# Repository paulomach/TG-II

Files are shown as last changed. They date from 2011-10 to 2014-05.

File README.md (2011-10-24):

Bicycle Transmission Library
============================

These are me bachelor thesis source files. The goal of this project is to create a library and a firmware for an [arduino](http://www.arduino.cc) automated bycicle transmission.

How to use it
-------------

Still have to write this.

Contributing
------------

In the current stage I'm not open to external contribution, mainly because now my goal is to customize it to my test scenario (and obtain my bachelor :) ). After I finished my thesisI'll be able to check your contibution. But if in the meantime you want to use the sources, please, do it. The code is released under [GPL v3](http://www.gnu.org/licenses/gpl-3.0.html).

Tips
----
Nice svg repository with circuit components [here](http://www.nemsim.com/ece395blimp/fritzing/parts/svg/core/breadboard/)

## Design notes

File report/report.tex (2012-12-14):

%
% report.tex - tex model of graduation work
% Version 0.1
%
% Author: Paulo S. Machado
% Date: 2S 2011
%
% Release under de GNU Public License v3.0 or greater
% This library is free software; you can redistribute it and/or
% modify it under the terms of the GNU General Public
% License as published by the Free Software Foundation; either
% version 3.0 of the License, or (at your option) any later version.
% 
% This template is distributed in the hope that it will be useful,
% but WITHOUT ANY WARRANTY; without even the implied warranty of
% MERCHANTABILITY or FITNESS FOR A PARTICULAR PURPOSE.  See the GNU
% General Public License for more details.
% 
% You should have received a copy of the GNU Lesser General Public
% License along with this template; if not, write to the Free Software
% Foundation, Inc., 51 Franklin St, Fifth Floor, Boston, MA  02110-1301  USA
%
\documentclass[a4paper,11pt]{article}

\input{preamble.tex}

\parindent 1cm

% \parskip 5pt

\begin{document}

% Title page and table of contents
\input{title/title.tex}

\lstset{frame=single,
    showstringspaces=false,
    extendedchars=true,
    language=C++,
    backgroundcolor=\color[rgb]{0.95,0.95,0.95},
    rulecolor=\color[rgb]{0.3,0.3,0.3},
    basicstyle=\scriptsize\ttfamily,
    commentstyle=\color[RGB]{105,105,105}\rmfamily\itshape,
    keywordstyle=\color[rgb]{0.6,0.0,0.0}\bfseries,
    stringstyle=\color[rgb]{0.6,0.4,0.4},
    identifierstyle=\color[rgb]{0.0,0.0,0.5},
    basicstyle=\tiny,
    numbers=left,
}

%%%
%
\section{Resumo}
\label{sec:resumo}
Um trabalho de graduação em Engenharia de Controle e Automação deve,
idealmente, abranger as três grandes áreas que originam a
formação\cite{enciclo}: Engenharia Elétrica (eletrônica, processamento de
sinais, circuitos elétricos e teoria de controle, etc); Engenharia
Mecânica (dinâmica, modelagem de sistemas, etc); e a Computação (automação,
controle discreto, etc).

A ideia deste projeto surgiu das observações diárias de ciclistas e do
uso da bicicleta, onde grande parte das pessoas não utiliza de
forma eficiente as marchas de suas bicicletas. Estas parecem ser
complicadas (\textit{mountain bikes} simples possuem pelo menos 18 marchas), de
difícil manejo, configuração e manutenção. Assim como em uma transmissão
automotiva, maus hábitos na sua operação -- esticar marchas, manter a mão
apoiada sobre a alavanca, entre outros -- causam desgaste precoce dos
componentes, esforços desnecessários (neste caso para ciclista) e até risco de
segurança.

O benefício primordial de qualquer automação (i.e. retirar do usuário o
controle ou parte do controle sobre o sistema que interage) é a melhora no
fluxo do processo devido ao aumento do controle sobre o sistema. Os
resultados deste benefício são, em alto nível, o aumento da qualidade,
repetibilidade e uniformidade, aplicação de estratégias ótimas de controle e
simplicidade na interação com utilizador.

Este relatório apresenta o desenvolvimento e resultados do trabalho proposto e
estudado na primeira disciplina de Trabalho de Graduação: a construção de um
protótipo funcional de um sistema de troca de marchas automatizados para
bicicletas convencionais. Neste primeiro trabalho foram construídas as base
teóricas e ferramentais para a construção de um protótipo funcional: construção
da bancada experimental; desenvolvimento da lógica; e estudo de soluções 
existentes. Ou seja, dados os objetivos do projeto -- software de controle,
circuito de controle, atuador mecânico e a junção destes no protótipo --
apresenta-se o caminho percorrido até o objetivo e os resultados alcançados.

O documento foi estruturado de forma a descrever o problema de engenharia, as
alternativas consideradas, escolhas e desenvolvimento de cada parte funcional do
protótipo final, testes e resultados.

\pagebreak
%%%
%
\section{Introdução}
\label{sec:intro}
A tônica no início do desenvolvimento deste projeto deu-se na escolha entre a
solução usando controle ou usando automação. A solução de controle -- através
do modelamento matemático do sistema físico -- é mais elegante, porém seu
desenvolvimento é mais complexo e depende de um sinal contínuo. A automação
-- análise dos sinais e programação de reações -- não é tão elegante e
eficiente, porém seu desenvolvimento é mais simples e pode ser orientada a
eventos. A resposta, seja ela qual for, passa obrigatoriamente pela análise do
problema físico.

\subsection{Análise do problema físico}
A transmissão ciclística convencional é apresentada na Figura
\ref{fig:transmissao}.
\begin{figure}[ht]
\begin{center}
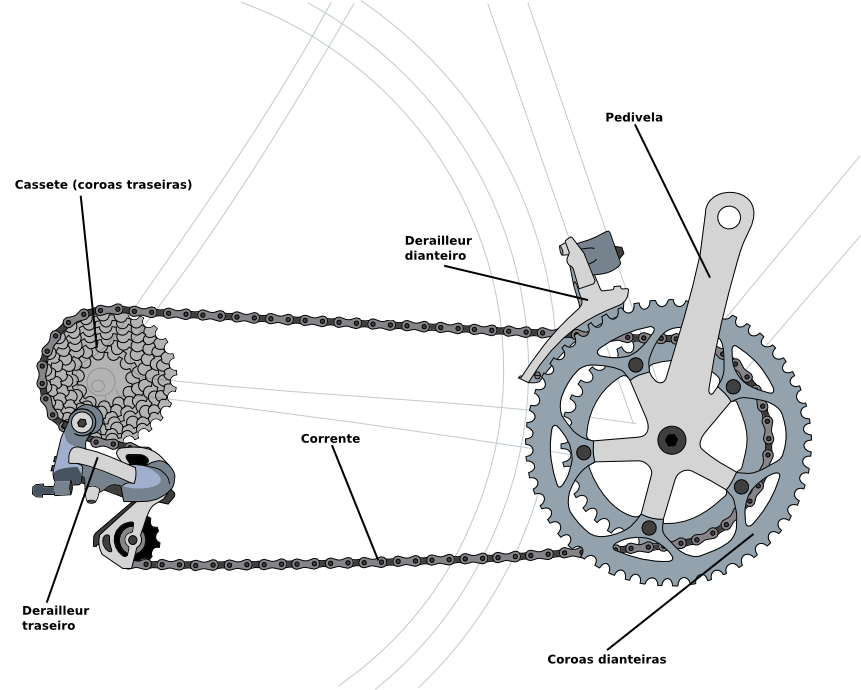
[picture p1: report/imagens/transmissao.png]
 
\end{center}
  \caption{Componentes de uma transmissão ciclística}
  \label{fig:transmissao}
\end{figure}
Podemos observar os principais componentes da transmissão, sendo na ordem em que
a energia é transmitida: o pedivela transmite o torque aplicado aos pedais pelo
ciclista às coroas dianteiras, que movimentam a corrente, que por sua vez,
transmite a energia às coroas traseiras (o conjunto destas é chamado de cassete,
nome que será usado no documento), conectadas a roda traseira, gerando a
movimento.

A relação de transmissão é determinada pela quantidade de dentes da coroa
traseira e dianteira de um engrenamento. Assim, a troca de marcha
(i.e. da relação de transmissão) é realizada pela mudança no engrenamento da
corrente com as coroas, tanto dianteiras  quanto traseiras. Portanto uma
bicicleta possui tantas marchas quanto forem a multiplicação da quantidade de
coroas no cassete pelas coroas dianteiras, por exemplo, quando há três coroas
dianteiras e seis coroas no cassete, a transmissão possui 3x6=18 marchas.
A mudança no engrenamento é realizado pelos
\textit{derailleurs}\footnote{\textit{Derailleur} é um termo francês que pode
ser traduzido como o ato do descarrilamento de um trem na ferrovia. O
dispositivo ganhou esse nome devido à semelhança com o evento ("descarrila" a
corrente).}, que mediante ao deslocamento longitudinal ao eixo da roda força a
corrente ser engrenada em outra coroa.

No desenvolvimento do protótipo (tratado como uma prova de conceito), por
simplicidade, a atuação foi limitada nos componentes da parte traseira
da transmissão, ou seja, apenas no \textit{derailleur} traseiro.
O esquema da Figura \ref{fig:derailleur} apresenta a visão traseira
do \textit{derailleur} e três exemplos de engrenamento.
\begin{figure}[ht]
\begin{center}
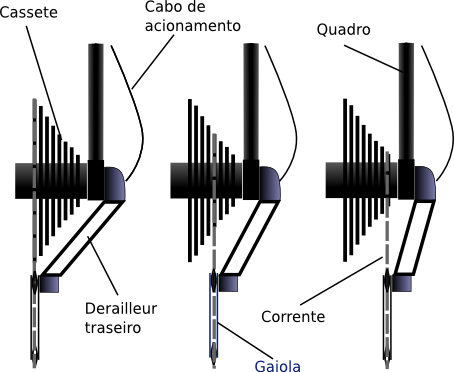
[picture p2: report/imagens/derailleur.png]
 
\end{center}
  \caption{Visão traseira de engrenamentos de um \textit{derailleur}.}
  \label{fig:derailleur}
\end{figure}
Na Figura \ref{fig:derailleur} temos, respectivamente, engrenado uma marcha
lenta (alto torque e baixa velocidade), uma marcha média e uma marcha rápida
(baixo torque e alta velocidade). O movimento da gaiola (componente do
\textit{derailleur}) se dá pela sua estrutura de braços paralelos do
\textit{derailleur} e é acionado via cabo, com retorno por mola. O cabo é
controlado pelo ciclista, geralmente por um sistema alavanca montado no guidão,
mas que também assume diversas outras formas, sempre com o objetivo de puxar ou
soltar o cabo, e genericamente chamado trocador (\textit{shifter}). O
trocador movimenta o cabo em estágios discretos, sendo cada estágio desse
correspondente ao engrenamento em uma coroa diferente.

O ciclista controla a pedalada de acordo com seu gosto, terreno e
velocidade. Logo, quando está em um aclive, procura puxar o cabo de forma a
engrenar as marchas mais lentas, e o oposto quando enfrenta um declive ou um
terreno que ofereça menos resistência, como por exemplo asfalto plano. O gosto e
biótipo do ciclista determinam o ponto da troca de marcha pela velocidade da
cadência (velocidade da pedalada). Por exemplo, o sete vezes campeão do
\textit{Tour de France}, Lance Armstrong, prefere pedalar em alta velocidade
(picos de 100-110 RPM), enquanto que outros ciclistas de sua categoria
dificilmente alcançam 90 RPM de
cadência\footnote{
\url{http://www.trifuel.com/training/bike/cycling-cadence-and-pedaling-economy}}
. Ciclistas amadores possuem limites bem inferiores. Portanto, uma premissa
básica
do projeto é a possibilidade do ajuste sobre os limites para a troca de marcha.

O resultado da análise do problema físico levou a escolha pela solução de
automação, preterindo o controle. A decisão baseou-se na observação de que o
sistema de uma transmissão de bicicleta, considerando as possíveis alternativas
para a forma de aquisição de dados de custo acessível, é orientado a
eventos e baseado em estados discretos.

\subsection{Revisão bibliográfica}
Uma ampla revisão bibliográfica foi realizada na primeira parte deste Trabalho
de Graduação, e não será repetida neste relatório. Vale ressaltar porém, que
pouca bibliografia acadêmica é produzida sobre o assunto. Por outro lado, o
desenvolvimento comercial é bastante prolífico, havendo em torno de quatro ou
cinco companhias multinacionais liderando os mercados globais de componentes e
diversos garagistas pensando e desenvolvendo soluções.

A maior dificuldade é como localizar documentação sobre uma solução tão
específica. A solução foi a utilização de duas bases de patentes:
USPTO\cite{uspto} e EPO\cite{epo}. O critério de escolha utilizado para
selecionar apenas os dois escritórios foi o fato de constituírem os dois maiores
mercados consumidores do mundo.

\subsection{Premissas do projeto}
\label{sec:premissas}
Após o estabelecimento do tipo de solução e de alguns requisitos mínimos, quatro
premissas simples foram estabelecidas para o protótipo. São:
\begin{itemize*}
  \item Baixo custo
  \item Adaptabilidade ao sistema existente
  \item Possibilidade de configuração de parâmetros
  \item Interface com usuário
\end{itemize*}

\pagebreak
%%%
%
\section{Desenvolvimento das partes}
\label{sec:partes}
Nesta seção são apresentadas as partes do projeto e como estas foram unidas. O
desenvolvimento deste projeto foi modular, o que permitiu na maior parte do
tempo trabalhar no hardware e no software de forma independente. As partes são:
\begin{itemize*}
  \item Bancada experimental
  \item Circuito de controle
  \item Protótipo Completo
  \item Algoritmo de Controle
\end{itemize*}

\subsection{Bancada experimental}
\label{sec:bancada}
A bancada experimental é um dos produtos principais da primeira parte deste
trabalho de graduação. Simular os sinais do sistema via algum tipo de software
ou kit é uma opção menos desejável, visto que o de desenvolvimento
do projeto com base em um sistema real não se apresentou como uma proposta
complicada ou muito cara. Desta forma, a solução elaborada no primeiro trabalho
foi usar uma bicicleta convencional e adaptá-la de forma a criar uma bancada de
testes. O resultado é apresentado na Figura
\ref{fig:bancada}.
\begin{figure}[ht]
 \begin{center}
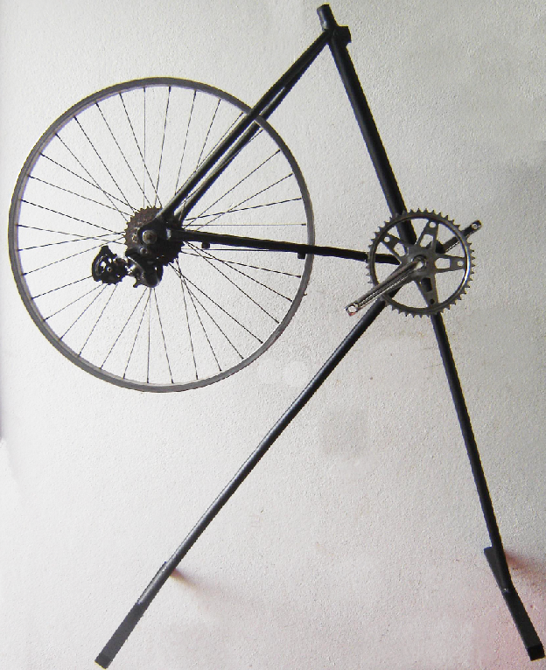
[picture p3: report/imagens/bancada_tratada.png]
  
 \end{center}
 \caption{Bancada experimental construída para o TG I}
 \label{fig:bancada}
\end{figure}
A bancada é uma meia bicicleta -- com a parte traseira, onde estão os
elementos da transmissão  -- onde foram soldados apoios, possibilitando
``pedalar no vazio'' e realizar os testes do projeto em um sistema real.

Foram diversos os problemas relativos a bancada, e surgiram no momento prévio
aos testes, quando os componentes da transmissão foram montados. As peças
disponíveis não eram compatíveis (corrente curta, coroa dianteira
não casou com o corrente), o que causou novos custos e atraso nos testes.
Superados os percalços, o resultado final é apresentado na Figura
\ref{fig:setup}. Nesta montagem estão presentes, além do sistema mecânico
completo da bicicleta, a montagem do servo motor e os ímas acoplados ao
pedivela e a roda.
\begin{figure}[h!]
\begin{center}
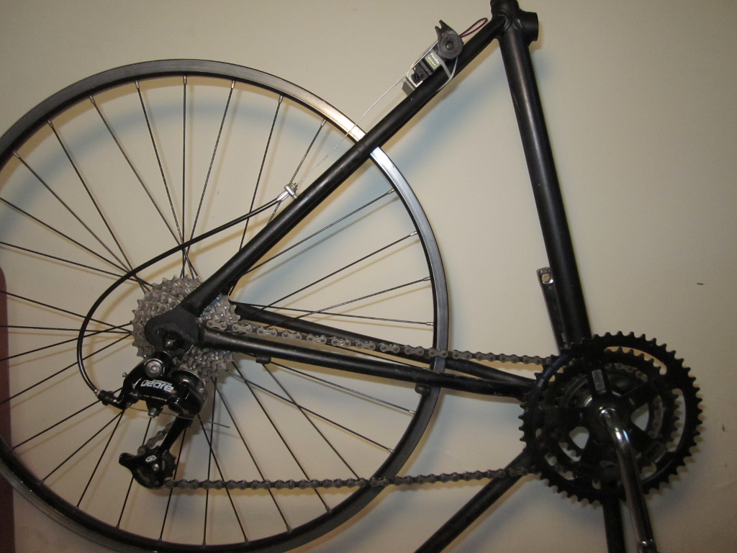
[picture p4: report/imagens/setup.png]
 
\end{center}
  \caption{Bancada pronta para teste}
  \label{fig:setup}
\end{figure}

%%%
%
\subsection{Circuito de controle}
\label{sec:montagem}
O circuito de controle foi montado sobre uma placa de prototipação (protoboard)
e seu esquema geral é apresentado na Figura \ref{fig:montagem}.
Os componentes podem ser separados em três grupos funcionais: saídas, controle
e entradas.
\begin{figure}[ht]
\begin{center}
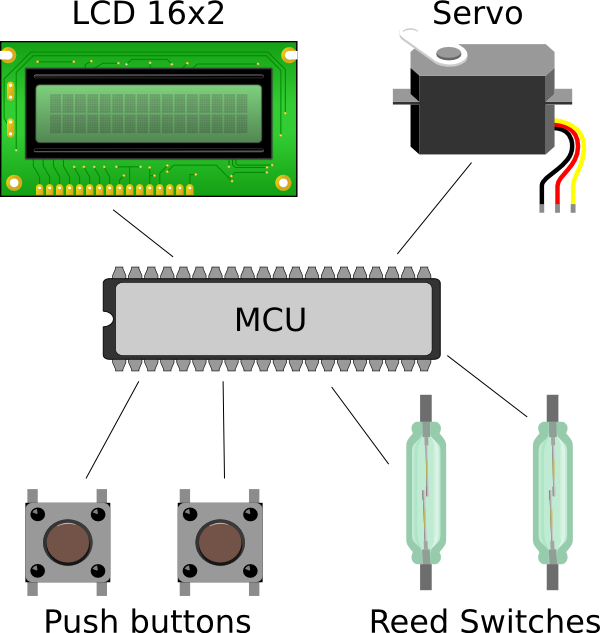
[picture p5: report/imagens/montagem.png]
 
\end{center}
  \caption{Componentes da montagem do circuito de controle}
  \label{fig:montagem}
\end{figure}
Nessa classificação são: saídas, servo motor e LCD (\textit{Liquid
Crystal Display}); controle, MCU (\textit{MicroControler Unit}); e entradas os
\textit{push buttons} e \textit{reed switch}. Os componentes utilizados e
detalhes da integração são descritos a seguir.

\subsubsection{Servo Motor}
\label{sec:servo}
O servo motor é o único atuador deste projeto, sendo responsável pela atuação
sobre o cabo do \textit{derailleur} e consequente troca de marchas. Duas
perguntas foram elaboradas para ajudar na definição de um atuador: Qual a
forma mais simples de atuar sobre um cabo utilizando um motor rotativo? Qual
tipo de motor é confiável e fácil de controlar? A reposta, encontrada a partir
do estudo realizado na primeira parte do trabalho de graduação, é o
acoplamento de uma polia (atuador sobre cabo) a um servo motor.

O raio da polia foi dimensionado de tal forma que, dado que um servo motor
rotaciona 180\textdegree, meia circunferência da polia seja deslocamento
suficiente para movimentar o \textit{derailleur} da menor a maior marcha.
Assim, definimos o raio da polia ($r_{polia}$), o número de marchas (n) e o
passo (p) como o deslocamento necessário do cabo de comando para a mudança de
uma marcha consecutiva, de tal forma que:
\begin{equation*}
  \frac{\displaystyle 2\pi r_{polia} }{\displaystyle 2} = (n-1)p
\end{equation*}
\begin{equation}
  r_{polia} = \frac{\displaystyle (n-1)p}{\displaystyle \pi}
\end{equation}
Para a bancada de testes, n=6 e p=3 mm. O raio ideal para a polia é:
\begin{equation}
 r_{polia} = \frac{\displaystyle (6-1)\times 3}{\displaystyle \pi} = 4,77~mm
\end{equation}
Porém, este resultado não foi utilizado, pois a construção de uma polia foi
preterida pela adaptação de um trocador manual (Figura \ref{fig:shifter}).
\begin{figure}[h!]
\begin{center}
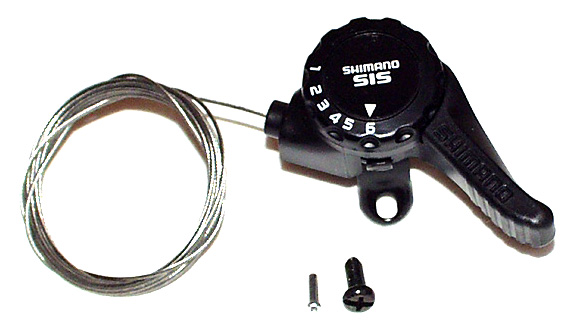
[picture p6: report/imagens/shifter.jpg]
 
\end{center}
  \caption{Trocador manual antes da adaptação}
  \label{fig:shifter}
\end{figure}

A polia interna deste trocador possui raio de 8,5 mm, o que por um lado aumenta
o intervalo de marchas disponível e a velocidade da troca (dada velocidade de
rotação constante do servo), por outro aumenta o requisito de torque no eixo. A
Figura \ref{fig:atuador} mostram a sequência da
adaptação.
\begin{figure}[h!]
 \centering
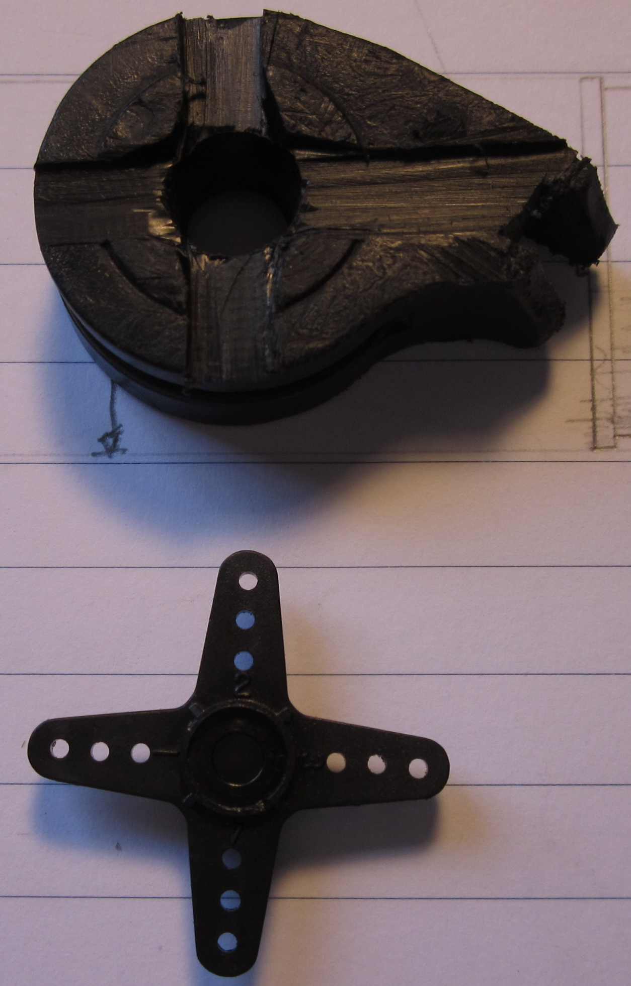
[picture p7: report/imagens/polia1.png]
  \subfloat[Partes]{} \hfil
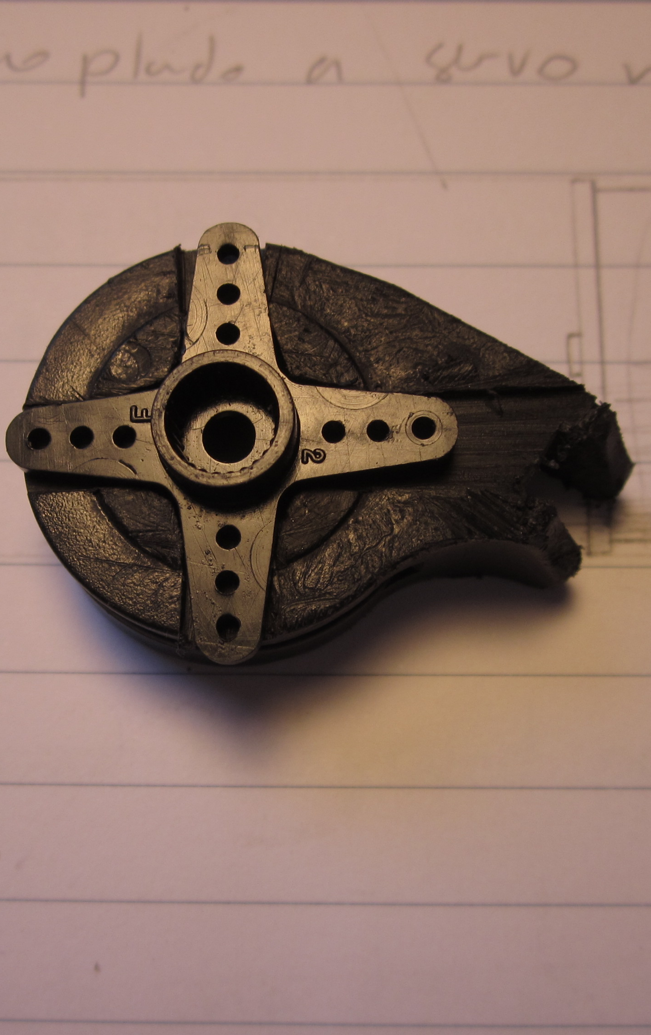
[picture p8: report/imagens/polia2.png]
  \subfloat[Partes Montadas]{} \hfil
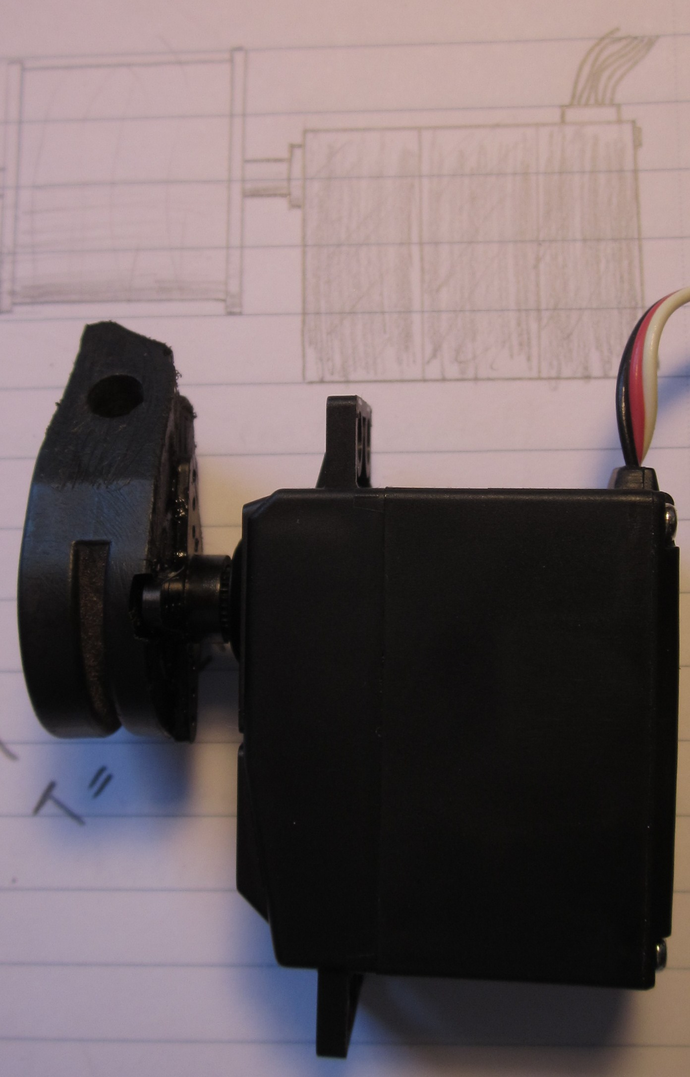
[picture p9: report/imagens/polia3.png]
  \subfloat[Atuador Completo]{}
  \caption{Sequência de adaptação do atuador}
  \label{fig:atuador}
\end{figure}

Pequenos servos RC (motores destinados ao mercado de hobbistas) são baratos,
fáceis de encontrar, robustos e seu controle é feito por um sinal PWM. O
servo motor escolhido foi um Futaba S3004, visto na Figura \ref{fig:
servo}. O S3004 possui rolamentos de esferas no eixo de saída, e torque de
4,1kg-cm a 6 volts, o que no SI equivale a $4,1 \times 9,81 \times 10^{-2} =
0,4022$ Nm.

\begin{figure}[ht]
 \begin{center}
  
 \end{center}
 \caption{Servo Futaba S3004}
 \label{fig: servo}
\end{figure}

Dois complicadores existem na utilização de servos motores\cite{servo}, em
relação a seu comportamento elétrico. O primeiro, como todo componente indutivo,
são os picos de corrente a cada mudança de posição, que podem drenar toda
corrente destinada ao controlador. O segundo complicador é o ruído, tanto gerado
pelo servo nas escovas do motor DC, quanto captado pelo cabo de sinal -- é comum
ver um servo "tremendo" quando em repouso -- pois o cabo do sinal PWM atua como
uma antena. Para mitigar estes efeitos a alimentação do servo foi isolada da
alimentação do resto do protótipo. O único cuidado adicional é manter as
referências no mesmo potencial, ou seja, manter o terra do circuito de controle
e do servo no mesmo potencial.

\subsubsection{Display LCD 16x2}
\label{sec:lcd}

Como o sistema propõe uma interface com o usuário, um display LCD foi escolhido
para executar este papel. A principal vantagem deste tipo de display é o baixo
consumo de energia, essencial em sistemas embarcados, devido a independência de
uma fonte de luz própria. O tamanho de 16 caracteres e duas linhas é suficiente
para mostrar as informações de velocidade imediata, a marcha engatada e o valor
da constante de ajuste, planejadas para esta interface.

O display utilizado é um JHD-162a\cite{lcd} de fabricante desconhecido e
facilmente encontrado no mercado, visto na Figura \ref{fig:lcd}.
\begin{figure}[ht]
\begin{center}
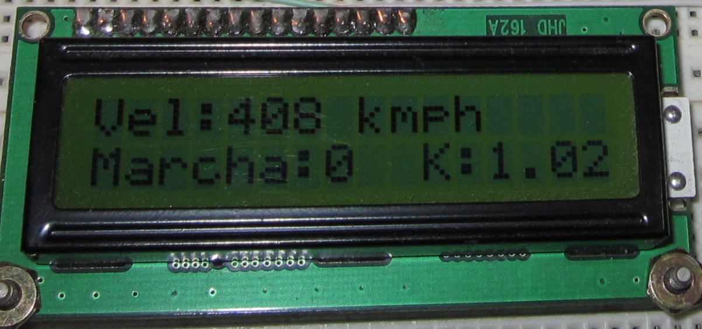
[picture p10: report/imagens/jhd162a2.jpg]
 
\end{center}
  \caption{Display LCD 16x2}
  \label{fig:lcd}
\end{figure}

A montagem do display não ofereceu nenhum problema, funcionando \textit{out of
the box}, o que é creditado a fartura de boa documentação encontrada na
Internet.

\subsubsection{Reed Switch}
\label{sec:reed}

A definição e uso de elementos sensores foi um dos elementos chave deste
projeto. Estes deveriam ser usados para a leitura de pulsos a cada revolução da
roda e do pedivela, gerando as informações de velocidades, básica ao algoritmo
de controle. As soluções analisadas foram:
\begin{itemize*}
 \item Sensor capacitivo
 \item Sensor indutivo
 \item \textit{Reed switch}
 \item Sensor de efeito HALL
\end{itemize*}
Os principais critérios de escolha, que permearam o projeto desde sua concepção,
foram simplicidade e custo. O escolhido foi o  \textit{reed switch}, que
oferece uma enorme margem de vantagem nos critérios escolhidos, e já é a
implementação padrão de computadores ciclísticos.

Um \textit{reed switch} é uma chave normalmente aberta constituída de duas
lâminas ferromagnéticas flexíveis, que sob influência de um campo magnético,
fecha o contato. A Figura \ref{fig:reed} apresenta o conceito é um
\textit{reed} como os utilizados.

\begin{figure}[h!]
 \centering
  \subfloat[Uma ampola \textit{reed} e
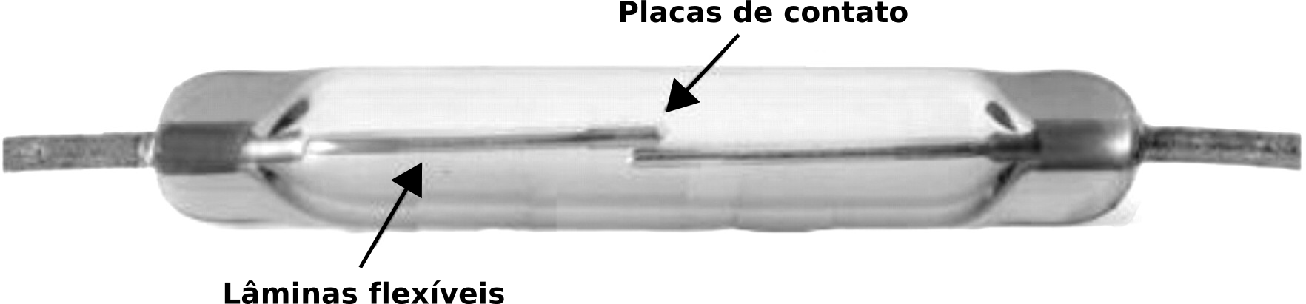
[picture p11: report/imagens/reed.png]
partes.]{} \hfil
  \subfloat[Contato fecha com
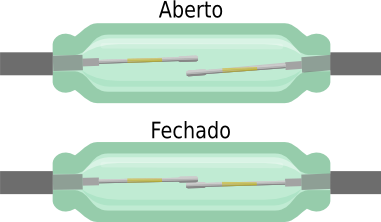
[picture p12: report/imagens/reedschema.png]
influência de campo magnético.]{}
  \caption{O \textit{Reed Switch}.}
  \label{fig:reed}
\end{figure}

Um problema grave dos \textit{reed switch} é o ruído gerado na
sua operação. Devido ao \textit{bouncing}\cite{reed} o sinal gerado precisa de
um tratamento para que possa ser lido corretamente. Foi considerado realizar o
\textit{debounce} do sinal de duas formas: via software; ou via hardware. A
primeira foi descartada pois as funções do programa responsáveis pelo
cálculo de velocidade seriam rotinas de interrupção, ou seja, eles devem ter uma
execução muito breve, caso contrário podem afetar a contagem de tempo do
sistema e uma função de \textit{debounce} em software envolve, inerentemente
algum \textit{delay}.

\begin{figure}[ht]
 \begin{center}
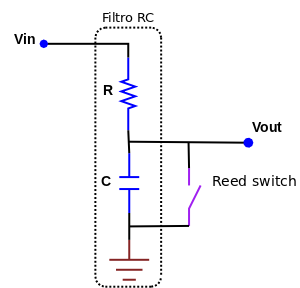
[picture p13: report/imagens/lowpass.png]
  
 \end{center}
 \caption{Filtro passa-baixa passivo acoplado ao \textit{reed switch}}
 \label{fig:lowpass}
\end{figure}

A alternativa foi implementar o \textit{debounce} em hardware, utilizando
um filtro passa-baixa passivo, que usa apenas um resistor e um capacitor, de
acordo com o esquema da Figura \ref{fig:lowpass}. O ruído de um \textit{reed
switch} comum está na faixa de 1500Hz a 2000Hz\cite{reed}. É possível estimar a
frequência máxima ($f_{max}$) de ativação dos \textit{reeds} a partir de um
limite de velocidade da roda ($v_{max} = 90 km/h = 25 m/s$):
\begin{equation}
  v = \omega r = 2\pi f r \Rightarrow v_{max} = 2\pi f_{max} r
\end{equation}
O diâmetro da roda com pneu foi medido em d=65cm = 0,65m. Portanto, para
velocidade máxima de 90 km/h:
\begin{equation}
  f_{max} = \frac{\displaystyle v_{max}}{\displaystyle \pi d} =
\frac{\displaystyle 25}{\displaystyle \pi 0,65} = 12,243 Hz
\end{equation}
Tomando a frequência de corte ($f_{c}$) dada pela relação,
\begin{equation}
  f_{c} = \frac{\displaystyle 1}{\displaystyle 2\pi\tau} \text{, onde } \tau =
RC
\end{equation}
igual a frequência máxima ($f_{max}$), diversas combinações de resistores e
capacitores são possíveis. Logo, o script \ref{code:filter} escrito em
linguagem pyhton\cite{python} foi usado para ajudar a dimensionar os
componentes, de acordo com o que foi adquirido (Sec. \ref{custos}) e o que foi
obtido.

\subsubsection{Push buttons}
\label{sec:buttons}
Os \textit{push buttons} têm a função de modificação da constante de ajuste do
sistema, incrementado ou decrementando seu valor. São elementos bastante
simples, que como os \textit{reed switch}, produzem ruído pelo fenômeno de
\textit{bouncing}. Porém como a sua aplicação não é crítica, não houve a
preocupação em tratar o sinal, pois o funcionamento do sistema praticamente não
é prejudicado por estas falhas.
\begin{figure}[ht]
\begin{center}
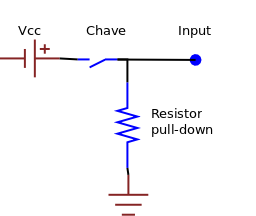
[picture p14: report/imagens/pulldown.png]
 
\end{center}
  \caption{Resistor \textit{pull-down}}
  \label{fig:pulldown}
\end{figure}

A única observação feita em relação a montagem dos \textit{push buttons} é a
topologia \textit{pull-down} do resistor, mostrado na Figura \ref{fig:pulldown}.
Este dispositivo é usado para limitar a corrente que passa do $V_{cc}$ para o
terra, e para garantir que o nível lógico seja coerente quando a chave conectada
está inativa, ``puxando'' a corrente para o terra. Tipicamente utiliza-se valor
de resistência de 10k$\Omega$, o que foi respeitado na montagem.

\subsubsection{Microcontrolador (MCU)}
\label{sec:mcu}
O microcontrolador utilizado é um ATMega168 20PU do fabricante
Atmel\textsuperscript{\textregistered}. O ATMega168\cite{atmega} é um
microcontrolador de 8 bits com 16K bytes de memória de programa e clock de 20MHz
e arquitetura RISC. O ATMega168 possui diversos periféricos dentre os quais são
de interesse para o projeto:
\begin{itemize*}
  \item 6 canais PWM
  \item 23 I/O programáveis (digitais e analógicos)
  \item Interrupção e \textit{wake-up} na borda de subida ou descida de sinal
  \item Interface serial para programação
\end{itemize*}

A utilização direta do microcontrolador requer diversos cuidados em relação a
sua alimentação, configuração de pinagem e recursos. Qualquer desenvolvedor de
sistemas embarcados sabe que este tipo de cuidado toma grande quantidade de
tempo e pode ser fonte de infindáveis problemas. Como resolver problemas de
natureza eletrônica e configuração de bits não é o propósito deste trabalho,
foi feita a escolha por uma plataforma de prototipagem que resolve grande parte
deste problemas: o Arduino\cite{arduino}\cite{oxer2009practical}.

O Arduino é uma plataforma de prototipagem \textit{open-source} (hardware e
software) que utiliza microcontroladores Atmel Mega168, Mega328 e Mega1280. Além
dos recursos providos pelo microcontrolador, são embarcados conversor
USB/Serial, tornando desnecessária uma porta serial no PC de desenvolvimento,
\textit{bournes} para conexão dos pinos de I/O, botão de \textit{reset},
cristal oscilador externo e entrada de alimentação. O circuito é capaz
de selecionar automaticamente qual fonte de alimentação utilizar (USB ou fonte
externa).

O modelo de escolhido para este trabalho foi o \textit{Duemilanove}, que
utiliza o microcontrolador ATMega168, e pode ser visto na Figura
\ref{fig:duemilanove}.
% FOTO Duemilenove
\begin{figure}[h]
\begin{center}
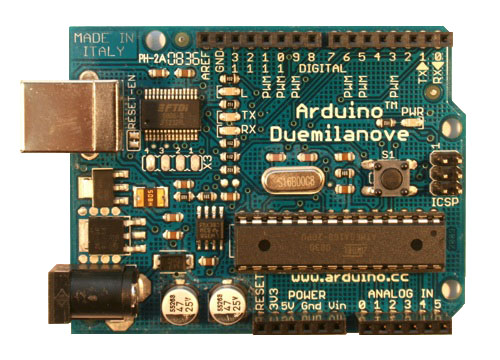
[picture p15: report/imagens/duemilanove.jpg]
 
\end{center}
  \caption{Arduino Duemilanove}
  \label{fig:duemilanove}
\end{figure}

A linguagem de programação utilizada é o C/C++, sendo que o compilador
utilizado foi o GNU Compiler Collection, o GCC\cite{gcc}. Uma das grandes
vantagem da utilização do GCC é ser multiplataforma, além do fato de ser
software livre. O Arduino provêm uma IDE e bibliotecas\cite{libs} para o
desenvolvimento de aplicações, adicionais as bibliotecas C fornecidas com o
compilador\cite{libc}, das quais foram utilizadas no projeto as bibliotecas
\textit{Servo} e \textit{LiquidCrystal}, responsáveis pela manipulação de servo
motores e display LCD, respectivamente.

%%%
%
\subsection{Protótipo}
\label{sec:prototipo}
O circuito completo do projeto, conforme esquematizado na Figura
\ref{fig:fritzing} é apresentado na Figura \ref{fig:circuito}. Um
componente adicional é o potenciômetro, usado para regular o contraste
do display LCD. Destaca-se na metade superior direita da Figura
\ref{fig:circuito} os circuitos para tratamento das entradas (dois filtros
passa-baixa e duas montagens de resistor \textit{pull-down}), e a alimentação
separada do servo motor para evitar a drenagem de corrente e ruído causado pelo
mesmo (Figura \ref{fig:fritzing}).

\begin{figure}
\begin{center}
 
\end{center}
  \caption{Esquema de montagem com protoboard}
  \label{fig:fritzing}
\end{figure}

\begin{figure}[hb!]
\begin{center}
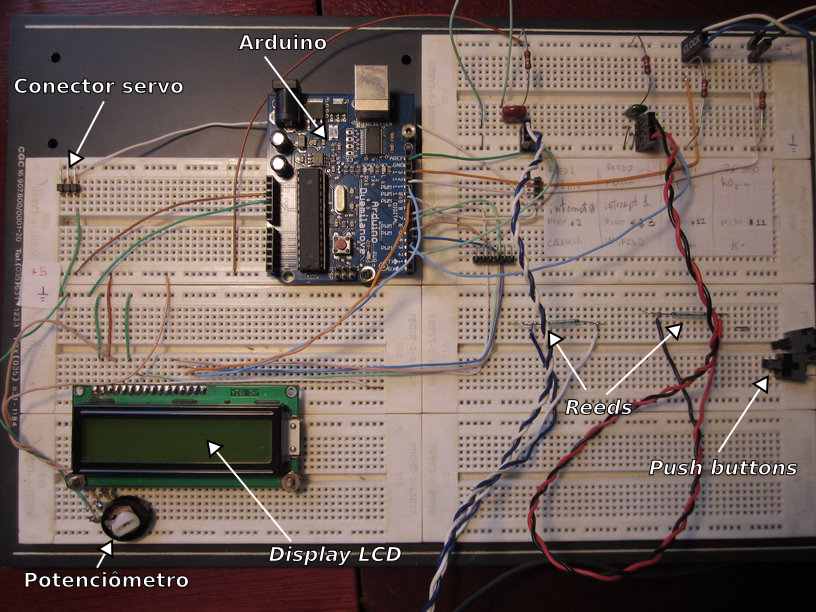
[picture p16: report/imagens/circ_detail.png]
 
\end{center}
  \caption{Circuito completo do Projeto}
  \label{fig:circuito}
\end{figure}

%%%
%
%\pagebreak

\subsection{Algoritmo de controle}
\label{sec:software}
A lógica do programa, elaborada ainda na primeira parte deste trabalho e que se
manteve fiel ao design original é apresentada na Figura \ref{fig:fluxograma1} e
descrita a seguir.

\begin{figure}[hb!]
 \begin{center}
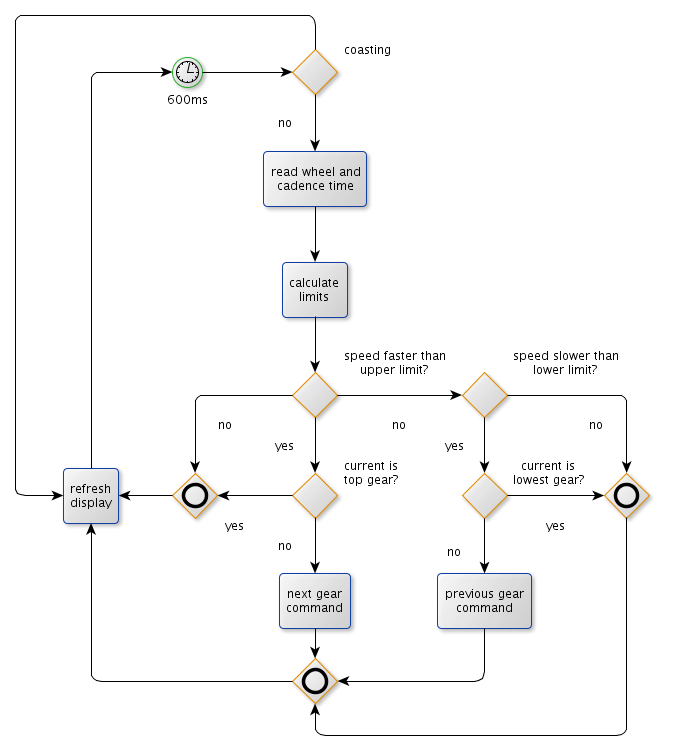
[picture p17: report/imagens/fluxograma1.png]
  
 \end{center}
 \caption{Lógica do programa de automação da transmissão}
 \label{fig:fluxograma1}
\end{figure}

\begin{description*}
  \item[Inicio:] início do programa.
  \item[Pedalando:] recebe informação da cadência e se nula, significa que o
  ciclista não está pedalando. Nesse caso, o sistema passa para o teste de
  bateria  e atualização do display. Caso contrário, segue para o passo
  seguinte, de  leitura de velocidade.
  \item[Leitura de velocidade:] armazena a leitura de velocidade instantânea do
  sensor de velocidade da roda traseira.
  \item[Calcula limites:] a partir de uma tabela de limites padrão e do valor da
  constante de velocidade (variável que armazena o valor do multiplicador dos
  limites, para adequação ao estilo de pedalada do ciclista), é calculado o
  limite de velocidade inferior e superior para a marcha presente.
  \item[Velocidade além do limite superior para a relação:] compara leitura de
  velocidade da roda traseira com o calculo do limite superior de velocidade
  para a marcha.
  \item[Velocidade abaixo do limite inferior para a relação:] compara leitura de
  velocidade da roda traseira com o calculo do limite inferior de velocidade
  para a marcha.
  \item[Próxima coroa disponível:] checa se a coroa atual engrenada é a última
  (coroa
  com menos dentes, ou seja, de maior velocidade).
  \item[Coroa anterior disponível:] checa se a coroa atual engrenada é a
  primeira (coroa com mais dentes, ou seja, de maior torque).
  \item[Movimenta \textit{derailleur} para próxima coroa:] caso a velocidade
  seja  maior que o limite superior da coroa atual e exista a próxima coroa, o
  \textit{derailleur}  é movimentado para engatar a coroa seguinte.
  \item[Movimenta \textit{derailleur} para coroa anterior:] caso a velocidade
  seja  menor que o limite inferior da coroa atual e exista a coroa anterior, o
  \textit{derailleur}  é movimentado para engatar a coroa anterior.
  \item[Checa bateria:] testa a carga da bateria e armazena informação. Esta é
  uma etapa muito importante em qualquer dispositivo embarcado, pois é da
  bateria que vem a energia necessária ao funcionamento do sistema.
  \item[Atualiza display:] atualização da interface com informação de velocidade
  instantânea, marcha engatada, e carga da bateria.
\end{description*}

\subsubsection{Estrutura do Código}
\label{sec:implemt}

A estrutura do código está dividida entre uma biblioteca, onde foram modeladas
classes para a representação do \textit{derailleur} e da roda de bicicleta, o
um programa principal. Esta opção se pauta em dois princípios, um técnico e
outro filosófico, respectivamente: utilizar a característica de representação do
mundo físico oferecida pelo programação orientada a objetos; a posterior
redistribuição do código como software livre\footnote{Todo código fonte deste
trabalho, inclusive este relatório, está disponível no site de hospedagem de
código github (\url{https://github.com/paulomach/TG-II}) sob a licença GPL
v3\cite{gpl}.}, visando a expansão e melhoria do projeto.

Fisicamente, os arquivos estão organizados:

\begin{verbatim}
BikeTransmission/
|-- BikeTransmission.cpp
|-- BikeTransmission.h
`-- keywords.txt
principal/
`-- principal.pde
\end{verbatim}

Os arquivos $BikeTransmission$ são a interface e implementação da biblioteca
que modela os elementos físicos do projeto. O arquivo $keywords.txt$ é o arquivo
de configuração para o destaque das palavras chaves introduzidas pela biblioteca
na IDE do Arduino. O arquivo $principal.pde$ é o programa principal onde a
biblioteca do projeto é usada.

A biblioteca \textit{BikeTransmission} modela basicamente duas classes que
representam a roda e o \textit{derailleur}. Um diagrama UML das classes está na
Figura \ref{fig:uml} a seguir.

\begin{figure}[h!]
\begin{center}
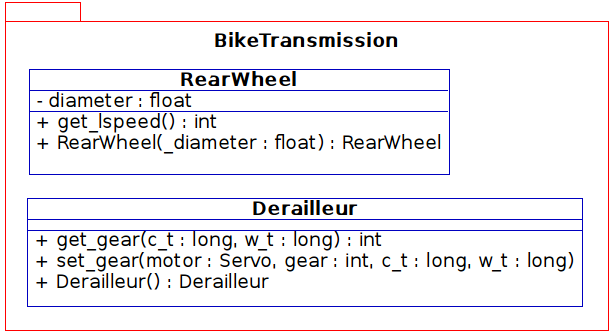
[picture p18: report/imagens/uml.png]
  
\end{center}
  \caption{Representação UML da biblioteca \textit{BikeTransmission}}
  \label{fig:uml}
\end{figure}

A roda traseira ($RearWheel$) possui um atributo representando o diâmetro da
roda, e um método para calcular a velocidade linear, além do método construtor.
O \textit{derailleur} possui dois métodos, um para obter a marcha engatada
($get\_gear$), e outro para selecionar uma nova marcha ($set\_gear$). Utiliza o
construtor padrão, pois não há configurações especiais.

O código integral está nos Anexos, nas seções \ref{code:api}, \ref{code:impl} e
\ref{code:main}, que são respectivamente, API (\textit{Application Programming
Interface}), a implementação da API e o código do programa principal que
utiliza a API. Os detalhes da implementação estão descritos na seção
\ref{sec:resultados} Testes e Resultados e especialmente na seção
\ref{sec:code_detail}, pois o desenvolvimento do código foi indissociável dos
testes.

\pagebreak
%%%
%
\section{Testes e Resultados}
\label{sec:resultados}

\subsection{Teste Preliminar}

Para início dos testes, antes de finalizada a bancada, um esquema de testes
físicos auxiliar era necessário. O objetivo é de alguma forma obter os sinais
que seriam obtidos pelo sistema real, ou seja, gerar os acionamentos dos
\textit{reed switch's} com as frequências esperadas para o sistema real.

Para satisfazer esse requisito de teste, uma plataforma foi desenvolvida
utilizando baterias, pequenos motores DC, potenciômetros (para regulação da
tensão nos motores, e logo sua velocidade), algumas peças de
LEGO\textsuperscript{\textregistered} para a montagem, e um par de ímãs
acoplados para o acionamento dos \textit{reed's}. A plataforma finalizada pode
ser vista em ação na Figura \ref{fig:test1}.

\begin{figure}[h!]
\begin{center}
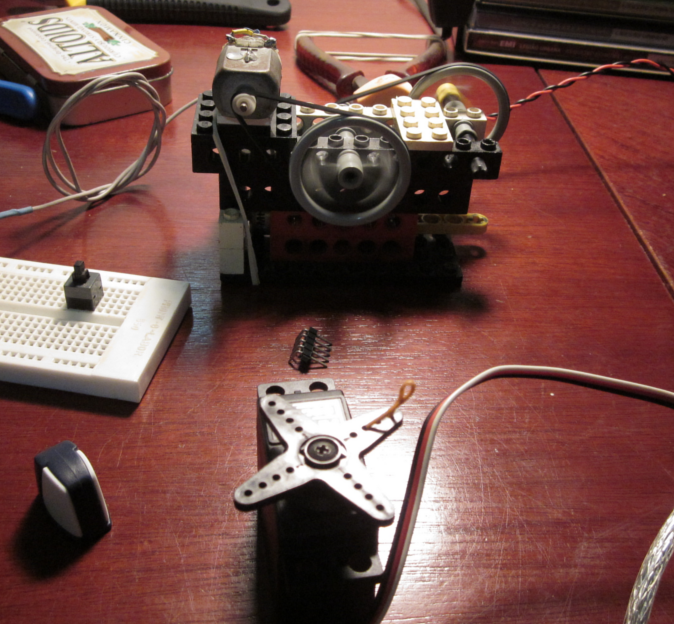
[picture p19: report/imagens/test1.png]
 
\end{center}
  \caption{Plataforma de testes}
  \label{fig:test1}
\end{figure}

Na parte de trás, o par trançado vermelho e preto é o cabeamento de um
\textit{reed}, enquanto que o \textit{protoboard} branco no centro à esquerda é
o circuito de controle da velocidade do motor DC. Acoplado a polia de trás há
um pequeno ímã de neodímio (também conhecido como ímã de terras raras),
extraído de um disco rígido. Este é um ímã poderoso considerando seu tamanho, e
gera o campo magnético necessário a ativação do \textit{reed} a até
aproximadamente 5 mm de distância.

Essa montagem permitiu a geração de um sinal em uma das duas entradas do
sistema, sendo que a segunda entrada foi gerada manualmente com outro ímã de
neodímio. As limitações desta montagem surgiram rapidamente. Gerar o sinal
manualmente se mostrou pouco conveniente, pois é bastate difícil manter um
intervalo regular manualmente. E visto que o potenciômetro disponível se
apresentou pouco amigável, se comportando mais como um interruptor do que como
uma resistência variável, não foi possível obter a variação na velocidade
desejada.

\subsubsection{Debugando o código}

Para visualizar o funcionamento e \textit{debug} do código, apenas observar a
saída do sistema (movimentação do servo motor) não é suficiente. A primeira
medida é a configuração do display LCD, mapeado como na Figura
\ref{fig:schemalcd}, contendo as informações mais básicas para a verificação do
sistema. A numeração na Figura é referente a posição de cada caractere do
display. Um exemplo do mapeamento já foi dado na Figura \ref{fig:lcd}.

\begin{figure}[h!]
\begin{center}
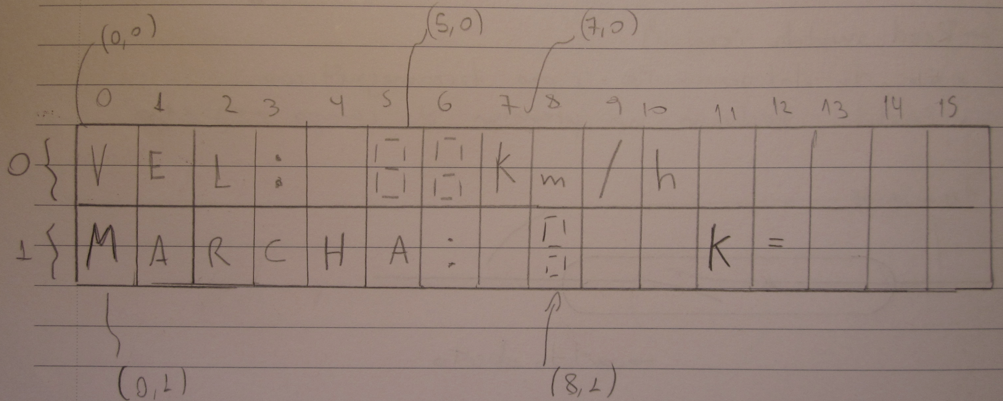
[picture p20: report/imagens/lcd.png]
  
\end{center}
  \caption{Esquema de configuração do display LCD}
  \label{fig:schemalcd}
\end{figure}

Este mapeamento é necessário para a codificação do display, apresentado no
trecho do código a seguir.
\begin{lstlisting}
  ...
  // LCD initialization
  LiquidCrystal lcd ( 7, 6, 5, 4, 8, 10 );
  ...
  // LCD static setup
  lcd.begin ( 16,2 );
  lcd.print( "start up..." );
  delay(2000);
  lcd.clear();
  lcd.print ( "Vel:" );
  lcd.setCursor ( 8,0 );
  lcd.print ( "kmph" );
  lcd.setCursor ( 0,1 );
  lcd.print ( "Marcha:" );
  lcd.setCursor ( 10,1 );
  lcd.print ( "K:" );
  ...
  // Update LCD
  void update_lcd() {
    lcd.setCursor ( 4,0 );
    lcd.print("    ");
    lcd.setCursor ( 4,0 );
    lcd.print ( wspeed );
    lcd.setCursor ( 7,1 );
    lcd.print ( gear );
    lcd.setCursor ( 12,1 );
    lcd.print ( K );
  }
...
\end{lstlisting}

O código da linha 3 cuida da instanciação de um objeto da classe LCD, usando os
pinos listados para a comunicação. Os comandos seguintes posicionam o cursor de
acordo com o mapeamento para então escrever a \textit{string} ou o valor
($lcd.setCursor$ e $lcd.print$).

Ainda assim, para o \textit{debug} do sistema mais informação é necessária. A
opção é a utilização dos recursos de comunicação serial do Arduino, que pode
transmitir dados em formato texto pela mesma porta USB usada para carregar e
alimentar o sistema. Para configurar e usar esta comunicação, o código:

\begin{lstlisting}
...
// Config Serial baud rate
Serial.begin ( 9600 );
...
/*
 * Serial debug output routine
 */
void update_serial() {
  if (debugLevel == 2) {
    Serial.print ( "Velocidade: " );    Serial.print ( wspeed );
    Serial.println(" kmph");
    Serial.print ( "Marcha: " );        Serial.println ( gear );
    Serial.print ( "Tempo roda: " );    Serial.print ( wtime );
    Serial.println (" ms" );
    Serial.print ( "Tempo cadencia: " );Serial.print ( ctime );
    Serial.println (" ms" );
    Serial.print ("K: ");               Serial.println (K);
    Serial.println("");
  }
}
...
\end{lstlisting}

Na linha 3 é configurado o \textit{baud rate}, que na comunicação serial
equivale a quantidade de bits transferida por segundo. O terminal serial
utilizado na leitura das mensagens precisa ter o mesmo \textit{baud rate}. A
partir da linha 8 a rotina de comunicação serial só transmite caso uma flag
seja configurada para tal.

Em qualquer parte do código pode ser adicionado um comando de impressão serial,
contendo o valor de uma variável, uma informação textual ou ambos. Um exemplo
dos das informações normalmente impressas na saída serial está na Figura
\ref{fig:serial}.

\begin{figure}[h!]
\begin{center}
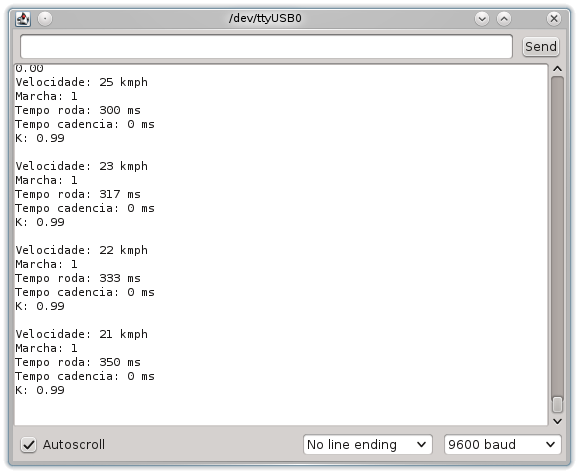
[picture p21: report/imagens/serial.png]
 
\end{center}
  \caption{Saída serial com informação de \textit{debug}.}
  \label{fig:serial}
\end{figure}

\subsubsection{Resultados}

Esta montagem preliminar foi útil especialmente para a calibração das entradas
realizando teste do \textit{debounce} dos \textit{reed switch} e botões,
redimensionando quando necessários os capacitores e resistores da montagem. A
geração manual de um sinal mostrou-se inapropriada, então logo que possível,
foi feita a montagem na bancada para testes reais.

\subsection{Teste de Bancada}

A bancada da Figura \ref{fig:setup} foi testada e após o primeiro
\textit{startup}, os sinais de entrada foram adquiridos corretamente, e os
sinais de saída apresentados no display e no monitor serial estavam coerentes.
Porém um detalhe do mais importante falhou: mesmo com uma nova marcha engatada,
nenhum movimento foi observado no \textit{derailleur}.

A conclusão é que o servo motor usado simplesmente não possui torque suficiente
(a força calculada para a combinação motor-polia é $\frac{4,1kgf-cm}{0.85cm} =
4,824kgf$, equivalente a 47,31N) para enrolar o cabo que movimenta o
\textit{derailleur}, o que é
discutido a seguir.

São duas fontes de resistência a este movimento, sendo a primeira o atrito do
cabo no conduíte, e a segunda e principal, a mola de retorno do
\textit{derailleur}. Três alternativas para contornar este problema foram
estudadas, sendo:
\begin{enumerate*}
  \item Diminuir o raio da polia, minimizando o torque necessário no eixo do
servo motor.
  \item Redimensionar a mola de retorno do \textit{derailleur} para um valor
menor da constante elástica.
  \item Redimensionar o servo motor, ou seja, utilizar um que forneça maior
valor de torque.
\end{enumerate*}

A primeira alternativa esbarrou em uma limitação ferramental, sendo bastante
complicado aprofundar a ranhura (destacada na Figura \ref{fig:ranhura}) da polia
do trocador manual de forma uniforme, isto é, de forma que o raio permanecesse
com o mesmo valor sempre.
\begin{figure}[!h]
\begin{center}
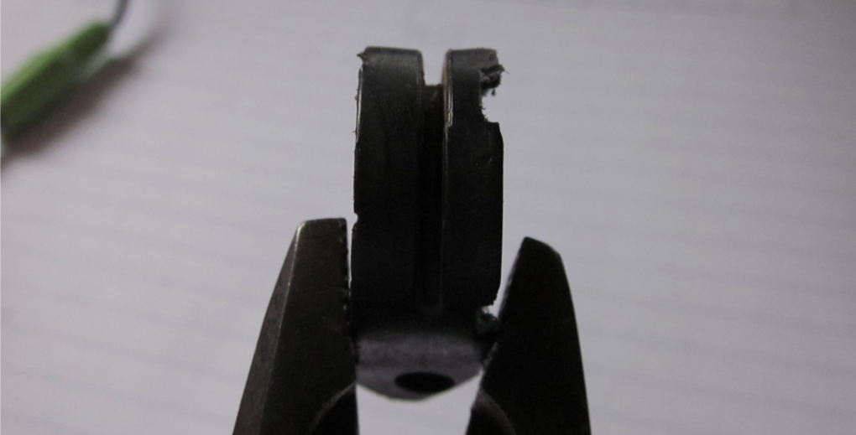
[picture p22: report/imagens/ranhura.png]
  
\end{center}
  \caption{Ranhura da polia do cabo de acionamento}
  \label{fig:ranhura}
\end{figure}

Manter o raio da polia uniforme é imprescindível pois o passo entre as coroas
no cassete são constantes, ou seja, caso variável o engate das marchas fica
comprometido. Sem uma forma de garantir a uniformidade, essa alternativa foi
deixada de lado no curto prazo.

Na consideração da segunda alternativa, foi questionado o porquê de um
\textit{derailleur} possuir uma mola de retorno de constante elástica
relativamente grande -- infelizmente não havia forma de medir seu valor, e não
há especificação disponível pelo fabricante, visto que constitui um dos
segredos do projeto. O valor é tal que possa garantir do \textit{derailleur} a
posição mínima, não importando as condições e configurações. Isto é, o
\textit{derailleur} é uma peça mecânica que fica completamente exposta aos
elementos, sendo que seu funcionamento tem que ser garantido o mesmo estando
este completamente limpo e lubrificado, ou cheio de barro. Há também o atrito no
cabeamento, que está sujeito a mesma variação de resistência do
\textit{derailleur}.

A segunda consideração é que, decidindo por uma intervenção na mola de retorno,
a construção da gaiola do \textit{derailleur} é projetada para não ser
desmontável (detalhe da Figura \ref{fig:derra}), com rebites e pinos
fixados por interferência. Ou seja, não há uma maneira simples de reconfigurar
este elemento, e caso houvesse, arrisca-se perder a robustez no seu
funcionamento.

Esta deixa de ser uma opção, e nesse sentido apenas uma completa
reformulação do \textit{derailleur} -- talvez abandonando completamente o
acionamento por cabo e a mola de retorno, acoplando um servo motor na sua
construção\footnote{A fabricante japonesa Shimano possui uma série de
\textit{derailleurs} eletrônicos de controle manual chamada Di2} -- deve
funcionar.

\begin{figure}[h!]
\begin{center}
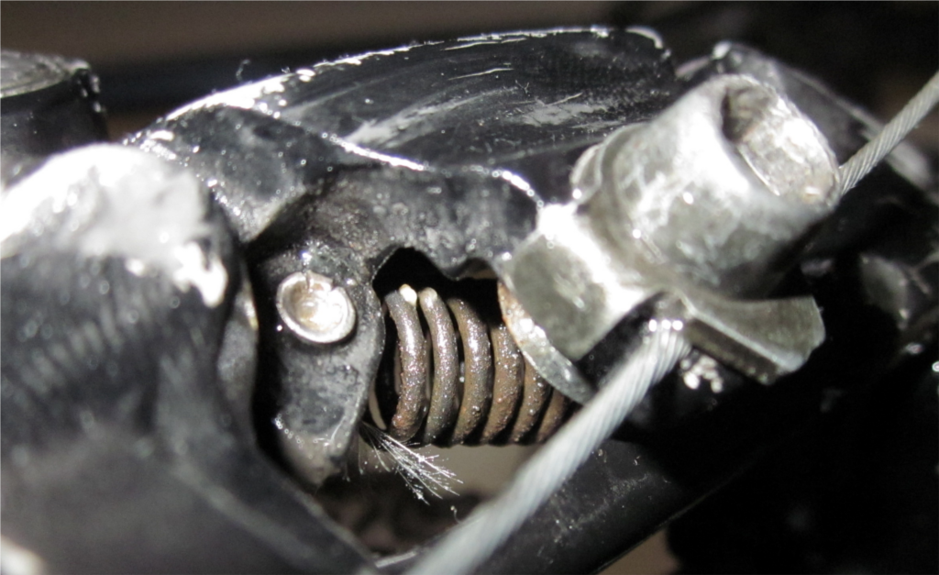
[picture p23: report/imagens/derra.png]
 
\end{center}
  \caption{Detalhe da construção da gaiola do \textit{derailleur}.}
  \label{fig:derra}
\end{figure}

A terceira opção é, entre todas, aquela que mais se aproxima da substituição de
um agente humano no controle, ou seja, um atuador capaz de produzir o torque
necessário para a troca de marchas. O que significa ir ao mercado e pesquisar
as opções disponíveis de servos de alto torque.

\subsubsection{Resolução de problemas}
Para prosseguir com os trabalhos, a tentativa foi pegar um velho
\textit{derailleur} e afrouxar a sua mola de retorno. Porém o acesso a mola não
é direto, e a mola foi completamente retirada. Ainda assim, alguma força de
retorno é necessária, então um elástico foi adaptado ao mecanismo, como
apresentado na Figura \ref{fig:adapt1}.

\begin{figure}[h!]
\begin{center}
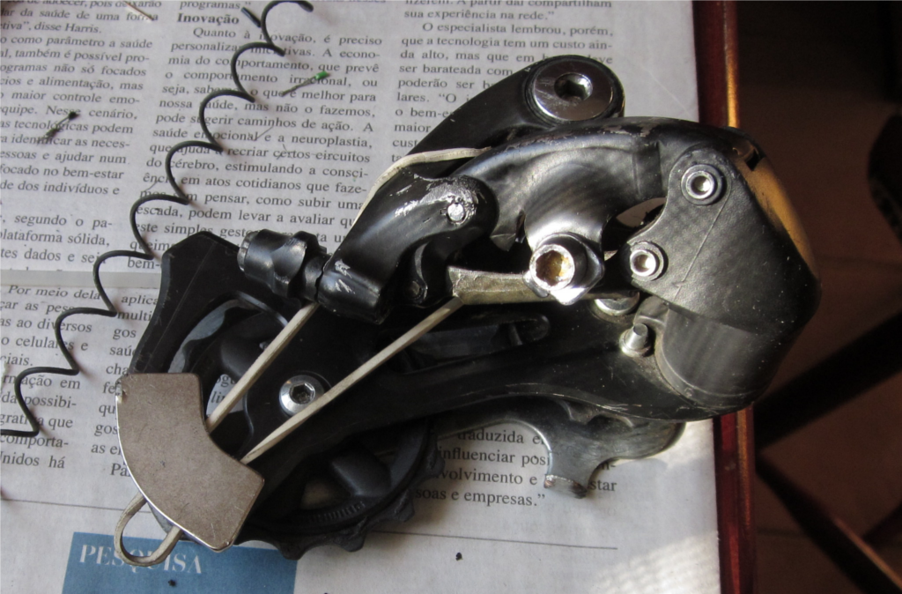
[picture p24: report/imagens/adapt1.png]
 
\end{center}
  \caption{Tentativa de adaptação de \textit{derailleur}.}
  \label{fig:adapt1}
\end{figure}

No canto esquerdo da imagem observa-se o que restou da tentativa de
afrouxamento da mola de retorno.

O sistema foi novamente testado, configurado para inicialmente estar na sexta e
última marcha, isto é, na marcha mais veloz e de menor torque. O comportamento
esperado é, dada uma velocidade mínima de cadência para que o estado não seja
considerado de \textit{coasting}, e cadência abaixo do ideal para a marcha, a
troca para a marcha superior fosse disparada. O que de fato foi observado numa
vã tentativa, já que novamente o torque do servo não foi suficiente para a
movimentação.

O proseguimento dos testes foi feito desacoplando o cabo do atuador e realizando
as trocas manualmente -- para obter as relações corretas entre as marchas.
Destes testes vieram correções e ajustes no software que é descrito na seção
seguinte.

\subsubsection{Detalhes da Implementação}
\label{sec:code_detail}
%TODO detalhes da implementação
O primeiro detalhe em destaque é a aquisição dos tempos de revolução da roda e
da cadência (rotação do pedivela). Houve a necessidade de usar rotinas de
interrupção para tratar os eventos gerados pelos \textit{reed's} e poder contar
o tempo entre cada evento. As interrupções, como dizem o nome, interrompem o
fluxo de execução do programa, chamando a rotina de interrupção para processar
o evento de forna aninhada. O requisito de qualquer rotina de interrupção é que
seja breve para que o fluxo geral do sistema não fique prejudicado.

Dois pinos de entrada digital 2 e 3 do Arduino foram associados às
rotinas para contar o tempo da cadência e da roda, respectivamente. A
associação é feita na borda de descida do sinal, tornando o sistema mais
robusto aos efeitos do \textit{bouncing} nos \textit{reed switches}. O
trecho de código a seguir, parte do arquivo $principal.pde$, é referente ao
tempo da cadência apenas, pois não há necessidade de reproduzir o código do
tempo da roda, visto que apenas alguns nomes são substituídos.
\begin{lstlisting}
// Pin config for interrupt routine
attachInterrupt ( 0, cadence_monitor, FALLING );
...
/*
 * cadence time interrupt
 * routine
 */
void cadence_monitor() {
  // first time log
  if ( c == false ) {
    ctimeLog[0] = millis();
    c=true;
  }
  else {
    ctimeLog[1] = millis();
    ctime = ctimeLog[1] - ctimeLog[0];
    ctimeLog[0] = ctimeLog[1];
  }
}
...
/*
 * timers reset routine
 */
void reset_timers() {
  unsigned long now = millis();
  if (now - wtimeLog[0] > RESET_TIMEOUT) {
    wtime = 0;
  }
  if (now - ctimeLog[0] > RESET_TIMEOUT) {
    ctime = 0;
  }
}
\end{lstlisting}
Na linha 2, a configuração necessária para associar a interrupção à rotina
$cadence_monitor$ na borda de descida. No linha 8, a rotina de interrupção
propriamente dita, guarda na primeira execução um valor de tempo (função
$millis()$ que retorna a contagem de tempo em milissegundos desde que o
microcontrolador foi iniciado) inicial. Da segunda chamada em diante, a
variável $ctime$ recebe o tempo da cadência através da subtração do registro
atual do tempo de execução com o registro anterior anterior, armazenado no
vetor $ctimeLog$.

Na linha 24, a função $reset\_timers$ é usada para zerar os contadores de tempo
de cadência e roda para que, caso a interrupção não seja disparada por um tempo
muito grande, o valor destes contadores não retornem valores absurdos.

O segundo detalhe fica em conta do fluxo de execução do algoritmo apresentado
na seção \ref{sec:software}. A implementação principal foi feita em um
\textit{looping} infinito (função $loop()$ na primeira linha). No trecho do
código do arquivo $principal.pde$:

\begin{lstlisting}
void loop() {
  ratio=float(ctime)/wtime;
  for (int i=0;i<6;i++) {
      if (closeto(ratio,validratios[i],TOLERANCE)) {
          gear = i+1;
      }
  }
  // check if coasting
  if (( ctime < CADENCE_MIN ) && ( ctime != 0)) {
    // if not act over transmission
    trocador.set_gear ( motor, gear, ctime, wtime, K );
  }
  wspeed = roda.get_lspeed ( wtime );
  update_lcd();
  update_serial();
  if ( digitalRead ( b1Pin ) == HIGH ) {
    K=K+0.01;
    if ( K >= 1.5 ) {
      K = 1.5;
    }
  }
  ...
}
/*
 * Return true if param is within
 * tolerance [%] of reference:
 */
boolean closeto(float param, float reference, float tolerance) {
    return ( (param >= (reference*(100-tolerance)/100) ) &&
      (param <= (reference*(100+tolerance)/100) ) );
}
\end{lstlisting}
A execução na linha 2 e no laço $for$ que segue calcula a relação entre o tempo
da cadência e tempo da roda, e atualiza o valor da marcha engatada, usando a
função $closeto$, linha 28, que retorna verdadeiro caso o valor da relação
esteja contido no vetor das relações esperadas $validratios$, com uma margem de
tolerância. Este vetor é obtido com o \textit{script} $ratios.py$ apresentado
na seção \ref{code:ratios} de Anexos, com base na relação de dentes de
engrenagem da transmissão usada.A rotina para determinação da marcha engatada é
originalmente parte do código da biblioteca, porém algum problema não
diagnosticado impedia que a chamada a esta função retornasse o valor correto.

O teste da linha 9, testa se o ciclista está "deslizando" (\textit{coasting}),
ou seja, em movimento inercial sem movimentar os pedais. Caso não esteja, a
execução segue apenas verificando os botões de configuração, lendo informação de
velocidade, e atualizando o display. Caso o ciclista esteja pedalando faz
chamada a função da biblioteca que se encarrega de testar e trocar a marcha,
quando necessário.

A configuração da constante K de ajuste dos limites de troca de marcha, feita
através dos botões está, para apenas um botão, nas linhas 16 a 21. Limitou-se a
configuração em mais ou menos 50\% do valor padrão.

O terceiro e mais importante detalhe da implementação é método de escolha e
mudança de marcha, da classe \textit{Derailleur}. Este método recebe o objeto
representando o servo motor, a marcha atual, os tempos de roda e cadência (i.e.
as velocidades) e a constante K de ajuste. O trecho a seguir mostra a
implementação.
\begin{lstlisting}
/*
 * Core method of the library. responsable
 * for choosing and setting a new gear
 * position
 */
void Derailleur::set_gear ( Servo motor, int gear, long int c_t, long int w_t,
float K ) {
    int cur_position = motor.read();
    int target_positon = round(STEP*gear);
    // make sure that derailleur is at expected position
    if (cur_position != target_positon) {
        motor.write(target_positon);
    }
    else {
        if ( ( c_t > CADENCE_MIN*K ) && ( gear != GEAR_MIN ) ) {
            // Hold position a little lower for a little time
            motor.write (round( STEP* ( gear - 1 ) *UP_OFFSET ));
            Serial.println("Mais torque!");
            delay(700);
            // and then leave in best position
            motor.write ( STEP* ( gear - 1 ) );
        } else if ( ( c_t < CADENCE_MAX*K ) && ( gear != GEAR_MAX ) ) {
            // Hold position a little higher for a little time
            motor.write (round( STEP* ( gear + 1 ) *DOWN_OFFSET ));
            Serial.println("Mais velocidade...");
            delay(700);
            // and then leave in best position
            motor.write ( STEP* ( gear + 1 ) );
        }
    }
}
\end{lstlisting}
O método inicia, na linha 11, confirmando se a marcha atualmente engatada, vinda
da relação de velocidades, é a mesma da posição do servo motor. Caso esteja,
prossegue para, na linha 15 testar a condição "Velocidade abaixo do limite
inferior para a relação" levando em consideração o fator K de ajuste, e a
condição "Coroa anterior disponível", como apresentado no fluxograma da Figura
\ref{fig:fluxograma1}. Da mesma forma, o código da linha 22 testa a condição
"Velocidade além do limite superior para a relação" levando em conta o fator K
de ajuste, e a condição "Próxima coroa disponível", também apresentado no
fluxograma do algoritmo.

Nas linhas 16 a 21 e 23 a 28, executa o comando para mudança de marcha
propriamente dito, para subida e descida respectivamente. A primeira ação
é movimentar o \textit{derailleur} um pouco além da posição de engate, em
seguida segurar esta posição por um curto tempo, para em seguida retornar a
posição da nova marcha engatada. Este é um pequeno truque usado em trocadores
manuais mais sofisticados para agilizar o engate.

\subsubsection{Resultados}
\label{sec:resultados}
%TODO mais resultados principais
Apesar de não ter sido possível testar o sistema em sua plenitude, a observação
da movimentação do servo motor, livre do cabeamento, e a visualização de dados
do programa na interface serial sugerem que, dada uma solução para as questões
mecânicas do atuador, a proposta do projeto pode ser alcançada.

Das premissas estabelecidas para o projeto (seção \ref{sec:premissas}), apenas
a segunda delas não pode ser considerada satisfeita (Adaptabilidade ao sistema
existente), visto que uma solução para a questão do atuador não está definida.

\pagebreak
%%%
%
\section{Conclusões}
\label{sec:conclusoes}
%TODO concluir Redundância da introdução Dificuldades

Em tempos de aumento da preocupação com questões ambientais, emissão de
poluentes, humanização das cidades, -- descaracterizadas e transformadas para
servir aos veículos automotores -- a bicicleta aparece como um agente
transformador. Seu apelo ecológico e à saúde, baixo custo e facilidade de uso
já a promovem ao veículo urbano do futuro, sendo que as diversas iniciativas de
incentivo ao uso de bicicletas comunitárias e/ou públicas ao redor do mundo, e
inclusive em nossa Universidade, estão aí para embasar esta tese. Neste
contexto, um projeto que visa evoluir e facilitar o uso da bicicleta merece um
pouco de atenção.

Muitas extensões podem ser feitas neste projeto, que é uma implementação
simplificada do conceito. A primeira adição proposta é um segundo
atuador para ser capaz de manipular o \textit{derailleur} das coroas dianteiras,
podendo utilizar toda a extensão das marchas disponíveis. Uma forma de incluir
esse atuador no algoritmo seria realizar as trocas nas coroas dianteiras quando
a mudança de velocidade for mais brusca. Isso porque a relação entre as coroas
dianteiras é tipicamente maior quando comparadas a relação entre as coroas do
cassete.

Uma segunda sugestão é um sistema de gerenciamento de energia, com baterias e
dínamos de roda, que seriam capazes de manter o sistema rodando apenas com a
própria geração de energia.

A terceira sugestão é a possibilidade de configuração de parâmetros em
\textit{runtime}, além de apenas a constante de ajuste K.

Como quarta, a adição de módulos de memória persistente para
que configurações não sejam perdidas a cada desligamento do sistema.

Finalmente, a quinta e última sugestão é a integração de um acelerômetro
eletrônico, de onde é possível ler a informação de inclinação do terreno. Como
em um automóvel, por vezes é interessante adiar a troca de marcha em subidas (a
"esticada") e postergar na descida.

Por fim e ao cabo, apesar da conclusão sem sucesso, a oportunidade de aplicar a
parte mais interessante de todo o conhecimento acumulado na graduação e bater
de frente em dificuldades da engenharia real foi bastante satisfatória. Ressalto
que este relatório encerra o trabalho de graduação, porém não encerra o projeto
do câmbio automático para bicicletas.

\begin{figure}[h!]
\begin{center}
 
\end{center}
\end{figure}

\pagebreak
%%%
%
\section{Anexos}
\label{sec:anexos}

%%%
%

%%%
%
\subsection{Custos do Projeto}
\label{custos}
Os custos dos materiais utilizados foram relativamente baixos. O
reaproveitamento de componentes previamente adquiridos, e principalmente, o
baixo custo dos componentes envolvidos possibilitaram minimizar esta soma. A
Tabela \ref{tab:custos} a seguir computa os componentes e ferramentas.
{
\newcommand{\mc}[3]{\multicolumn{#1}{#2}{#3}}
\begin{table}[ht]
\begin{center}
\caption{Custos do projeto}
\label{tab:custos}
\begin{tabular}{lc}
\mc{1}{c}{\textbf{Material}} & \textbf{Preço (R\$)}\\\hline
Movimento central & R\$ 12,00\\
Display LCD 16x2 & R\$ 20,00\\
Arduino Duemilenove & R\$ 40,00\\
Servo Futaba s3004 & R\$ 12,00\\
Ferro de solda 100W & R\$ 18,00\\
\textit{Reed switch} (5x) & R\$ 3,45\\
Resistores 10k (6x) & R\$ 0,78\\\hline
\textbf{Total} & \textbf{R\$ 106,23}\\\hline
\end{tabular}
\end{center}
\end{table}
}

%%%
%
\subsection{Código Fonte}
\label{codigo}

\subsubsection{API da Biblioteca \textit{BikeTransmission}}
\label{code:api}
\textit{BikeTransmission.h}:
\lstinputlisting{../BikeTransmission/BikeTransmission.h}

\subsubsection{Implementação da Biblioteca \textit{BikeTransmission}}
\label{code:impl}
\textit{BikeTransmission.cpp}:
\lstinputlisting{../BikeTransmission/BikeTransmission.cpp}

\subsubsection{Programa principal}
\label{code:main}
\textit{principal.pde}
\lstinputlisting{../principal/principal.pde}

%%
%
\lstset{frame=single,
    language=Python,
    basicstyle=\ttfamily\small,
    otherkeywords={=, +, [, ], (, ), \{, \}, :},
    keywordstyle=\color{blue},
    stringstyle=\color{red},
    showstringspaces=false,
    emph={class, pass, in, for, while, if, is, elif, else, not, and, or,
    def, print, exec, break, continue, return},
    emphstyle=\color{black}\bfseries,
    emph={[2]True, False, None, self},
    emphstyle=[2]\color{key},
    emph={[3]from, import, as},
    emphstyle=[3]\color{blue},
    upquote=true,
    morecomment=[s]{"""}{"""},
    commentstyle=\color[RGB]{105,105,105}\slshape,
    basicstyle=\tiny,
}
\subsubsection{Cálculo de Relação entre marchas}
\label{code:ratios}
\textit{ratios.py}
\lstinputlisting{../ratios.py}

\subsubsection{Cálculo de Filtro RC}
\label{code:filter}
\textit{capacitance\_n\_resistance.py}
\lstinputlisting{../capacitance_n_resistance_calc.py}

\pagebreak
%%%
%
% bibliografia precisa ser explicitamente adicionada ao sumário:
\cleardoublepage
\renewcommand*{\refname}{}
\section{Referências}

\bibliographystyle{unsrt}
\bibliography{report}

\end{document}

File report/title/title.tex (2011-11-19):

%
% title.tex - tex model of graduation work
% Version 0.1
%
% Author: Paulo S. Machado
% Date: June 2010
%
% Release under de GNU Public License v3.0 or greater
% This library is free software; you can redistribute it and/or
% modify it under the terms of the GNU General Public
% License as published by the Free Software Foundation; either
% version 3.0 of the License, or (at your option) any later version.
% 
% This template is distributed in the hope that it will be useful,
% but WITHOUT ANY WARRANTY; without even the implied warranty of
% MERCHANTABILITY or FITNESS FOR A PARTICULAR PURPOSE.  See the GNU
% General Public License for more details.
% 
% You should have received a copy of the GNU Lesser General Public
% License along with this template; if not, write to the Free Software
% Foundation, Inc., 51 Franklin St, Fifth Floor, Boston, MA  02110-1301  USA
%
% Title page
\begin{titlepage}
\begin{center}
 
% Header
\\[1cm]
\textsc{\LARGE Universidade Estadual de Campinas}\\[0.3cm]
\textsc{\LARGE Faculdade de Engenharia Mecânica}\\[0.3cm]
\textsc{\LARGE ES952 - Trabalho de Graduação II}\\[3.0cm] 
\textsc{\Large Relatório de Atividades} \\[0.2cm]

% Title
\hfill
\textsf{ \LARGE \bfseries Desenvolvimento de um câmbio automático para
bicicletas}

\vfill
% Author and project
\begin{minipage}{0.49\textwidth}
\begin{flushleft} \large
\emph{Autor:}\\
Paulo Silveira Machado \\
RA: 024831
\end{flushleft}
\end{minipage}
\begin{minipage}{0.5\textwidth}
\begin{flushright} \large
\emph{Orientador:} \\
Prof. Dr. Luiz Otávio Saraiva Ferreira\\
Faculdade de Engenharia Mecânica
\end{flushright}
\end{minipage}
 
\vfill
 
% Botton
{\large 2\textordmasculine ~Semestre/2011}
\end{center}
 
\end{titlepage}

% Table of contents
\tableofcontents

% List of figures
\listoffigures

% List of tables
\listoftables
\pagebreak

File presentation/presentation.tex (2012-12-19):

\pdfminorversion=4
\documentclass{beamer}

\usepackage[utf8x]{inputenc}
\usepackage[T1]{fontenc}
\usepackage{default}
\usepackage[portuges,brazil]{babel}
\usepackage{graphicx}
\usepackage{amsmath}
\usepackage{subfig}
\usetheme[compress]{Singapore}

\DeclareGraphicsExtensions{.jpg,.jpeg,.png}
\graphicspath{{../report/imagens/}}

\begin{document}

% capa
\begin{frame}[plain]
  \begin{center}
    \\[0.5cm]
    \textsc{\large Universidade Estadual de Campinas}\\%[0.3cm]
    \textsc{\large Faculdade de Engenharia Mecânica}\\%[0.3cm]
    \textsc{\large ES952 - Trabalho de Graduação II}\\[1.0cm]

    \textsf{  \bfseries Desenvolvimento de um câmbio automático
  para bicicletas}

    \vfill
    % Author and project
    \begin{minipage}{0.4\textwidth}
    \begin{flushleft} \tiny
    \emph{Autor:}\\
    Paulo Silveira Machado \\
    RA: 024831
    \end{flushleft}
    \end{minipage}
    \begin{minipage}{0.4\textwidth}
    \begin{flushright} \tiny
    \emph{Orientador:} \\
    Prof. Dr. Luiz Otávio Saraiva Ferreira\\
    Faculdade de Engenharia Mecânica
    \end{flushright}
    \end{minipage}

  \end{center}

\end{frame}

% agenda
\begin{frame}[plain]
  \frametitle{Agenda}
  \tableofcontents
\end{frame}

% apresentação objetivos
\section{Apresentação}
\subsection{}
\begin{frame}
  \frametitle{Apresentação}
  \begin{itemize}
    \item Objetivo: Construir um protótipo funcional
    \item Premissas:
    \begin{enumerate}
      \item Baixo custo
      \item Adaptabilidade
      \item Configuração de parâmetros
      \item Interface com usuário
    \end{enumerate}

  \end{itemize}

\end{frame}

% justificativa
\section{Motivação}

\subsection{}
\begin{frame}
 \frametitle{Motivação}

  \begin{itemize}[<+->]
    \item Apelo ecológico da bicicleta
    \item Apelo à saúde
    \item Esporte de escolha (conhecimento de causa)
    \item Observações diárias
  \end{itemize}

\end{frame}

\section{Estudo}
% Problema físico
\subsection{}
\begin{frame}
  \frametitle{A transmissão ciclística}
  Destaque:
  \begin{itemize}
    \item ``Descarrilamento''
    \item \textit{Coasting}
    \item Mola de retorno
    \item Cabeamento
  \end{itemize}
\end{frame}

% bibliografia
\subsection{}
\begin{frame}
  \frametitle{Fontes de Estudo}
  \begin{itemize}%[<+->]
    \item Literatura Acadêmica
    \item Revistas especializadas
    \item Base de Patentes
      \begin{enumerate}
        \item EPO
        \item USPTO
      \end{enumerate}
  \end{itemize}
\end{frame}

\begin{frame}
  \frametitle{Fontes de Estudo}
  \begin{itemize}%[<+->]
    \item Literatura Acadêmica - Inexistente
    \item Revistas especializadas
    \item Base de Patentes
      \begin{enumerate}
        \item EPO
        \item USPTO
      \end{enumerate}
  \end{itemize}
\end{frame}

\begin{frame}
  \frametitle{Fontes de Estudo}
  \begin{itemize}%[<+->]
    \item Literatura Acadêmica
    \item Revistas especializadas - Pouca disponibilidade
    \item Base de Patentes
      \begin{enumerate}
        \item EPO
        \item USPTO
      \end{enumerate}
  \end{itemize}
\end{frame}

\begin{frame}
  \frametitle{Fontes de Estudo}
  \begin{itemize}%[<+->]
    \item Literatura Acadêmica
    \item Revistas especializadas
    \item Base de Patentes - Muita informação
      \begin{enumerate}
        \item EPO
        \item USPTO
      \end{enumerate}
  \end{itemize}
\end{frame}

\section{Desenvolvimento}
\subsection{}
\begin{frame}
  \frametitle{Bancada Experimental}
  \begin{itemize}
    \item Relativa facilidade na construção
    \item Para obter os sinais do sistema real
    \item Para atuar sobre sistema real*
  \end{itemize}
\end{frame}

\begin{frame}
 % fotos construção
\begin{figure}
 \centering
  \subfloat{} \hfil
  \subfloat{} \hfil
  \subfloat{} \hfil
 \end{figure}
\end{frame}

\subsection{}
\begin{frame}
 \frametitle{Circuito de Controle}
  \begin{itemize}
    \item Microcontrolador
    \item Circuito de aquisição de sinais
    \item Montagem do atuador
  \end{itemize}
\end{frame}

\subsection{}
\begin{frame}
  \frametitle{Microcontrolador}
  \begin{itemize}
  \item Arduino Duemilenove (AtMega168):
    \begin{enumerate}
      \item PWM
      \item I/O Digitais/Analógicas
      \item 2 pinos de interrupção (\textit{falling/rising})
      \item Interface Serial
    \end{enumerate}
  \end{itemize}
\begin{figure}[h]
\begin{center}
 
\end{center}
\end{figure}
\end{frame}

\subsection{}
\begin{frame}
  \frametitle{Aquisição de sinal}
  \begin{itemize}
    \item \textit{Reed Switchs}
    \begin{enumerate}
      \item Pró - Simples e barato
      \item Contra - \textit{Bouncing}
    \end{enumerate}
  \end{itemize}

\begin{figure}[h!]
 \centering
  \subfloat{} \hfil
  \subfloat{}
  \label{fig:reed}
\end{figure}
\end{frame}

\begin{frame}
 \frametitle{\textit{Debounce} em hardware}
  \begin{itemize}
    \item Filtro Passa-Baixa passivo RC
    \item Ruído de um \textit{reed} típico entre 1500-2000Hz
    \item Frequência máxima de ativação:
    \begin{equation}
  v = \omega r = 2\pi f r \Rightarrow v_{max} = 2\pi f_{max} r
\end{equation}
O diâmetro da roda com pneu foi medido em d=65cm = 0.65m. Para 90
km/h (25 m/s):
\begin{equation}
  f_{max} = \frac{\displaystyle v_{max}}{\displaystyle \pi d} =
\frac{\displaystyle 25}{\displaystyle \pi 0.65} = 12.243 Hz
\end{equation}

  \end{itemize}
\end{frame}

\begin{frame}
  \frametitle{Filtro RC passa-baixa, resistor \textit{pull-up}}
  \begin{center}
    \begin{figure}
      
    \end{figure}
  \end{center}
\end{frame}

\subsection{}
\begin{frame}
  \frametitle{Atuador}
  \begin{itemize}
    \item Servo Futaba S3004
    \item 4.1 kgf-cm a 6V (0.4022 Nm)
  \end{itemize}
\begin{figure}[ht]
 \begin{center}
  
 \end{center}
\end{figure}
\end{frame}

\subsection{}
\begin{frame}
\begin{figure}
 \centering
  \subfloat[Partes]{} \hfil
  \subfloat[Partes Montadas]{} \hfil
  \subfloat[Atuador Completo]{}
\end{figure}
\end{frame}

\subsection{}
\begin{frame}
 \frametitle{Algoritmo de Controle}
  \begin{itemize}
    \item Entrada
    \begin{enumerate}
     \item Velocidade/tempo roda
      \item Velocidade/tempo pedalada
      \item Configuração
    \end{enumerate}
    \item Saída
     \begin{enumerate}
      \item Comando para atuador
      \item Atualização da interface
     \end{enumerate}

  \end{itemize}

\end{frame}

\begin{frame}[plain]
  \begin{figure}
    \begin{center}
      
    \end{center}
  \end{figure}
\end{frame}

\begin{frame}
  \frametitle{Estrutura do Código}
  \begin{itemize}
    \item Orientação a objetos
    \item Modelagem partes físicas
  \end{itemize}
  \begin{figure}[h!]
    \begin{center}
      
    \end{center}
  \end{figure}
\end{frame}

\section{Testes e Resultados}
\subsection{}
\begin{frame}
 \frametitle{Teste e Resultados}

Teste Preliminar

  \begin{itemize}
    \item Plataforma para geração dos sinais de entrada
    \item Observação inicial do comportamento do sistema
    \item Calibração dos resistores e capacitores do filtro RC
  \end{itemize}
\end{frame}

\subsection{}
\begin{frame}
 \frametitle{Teste e Resultados}

Teste na Bancada
\begin{itemize}
 \item Detalhes da implementação
    \begin{enumerate}
      \item Rotinas de interrupção - velocidades
      \item Condição de \textit{coasting}
      \item Estratégia para troca de marcha
    \end{enumerate}

\end{itemize}
\end{frame}

\subsection{}
\begin{frame}
 \frametitle{Problemas}
Questão mecânica do atuador
  \begin{itemize}
   \item Torque motor insuficiente
    \begin{enumerate}
      \item Diminuir raio polia
      \item Redimensionamento servo motor
      \item Substituição mola de retorno
    \end{enumerate}
  \end{itemize}
\end{frame}

\section{Conclusão}
\subsection{}
\begin{frame}
  \frametitle{Conclusão}

Premissa custo:

  \newcommand{\mc}[3]{\multicolumn{#1}{#2}{#3}}
  \begin{table}[ht]
    \begin{center}
      \begin{tabular}{lc}
	\mc{1}{c}{\textbf{Material}} & \textbf{Preço (R\$)}\\\hline
	Movimento central & R\$ 12,00\\
	Display LCD 16x2 & R\$ 20,00\\
	Arduino Duemilenove & R\$ 40,00\\
	Servo Futaba s3004 & R\$ 12,00\\
	Ferro de solda 100W & R\$ 18,00\\
	\textit{Reed switch} (5x) & R\$ 3,45\\
	Resistores 10k (6x) & R\$ 0,78\\\hline
	\textbf{Total} & \textbf{R\$ 106,23}\\\hline
      \end{tabular}
    \end{center}
  \end{table}
\end{frame}

\begin{frame}
 \frametitle{Conclusão}

Premissa adaptabilidade:

\begin{itemize}
  \item Atuador mal dimensionado
  \item Completa reformulação do atuador
\end{itemize}
\end{frame}

\begin{frame}
  \frametitle{Conclusão}
Premissa configuração de parâmetros
  \begin{itemize}
    \item Apenas um parâmetro configurável
    \item Outros parâmetros de interesse:
     \begin{itemize}
        \item Tolerância na determinação de marcha
        \item Cadência máxima e mínima
        \item Diâmetro da roda
     \end{itemize}
  \end{itemize}

\end{frame}

\begin{frame}
  \frametitle{Conclusão}
Premissa interface
  \begin{itemize}
   \item Funções de computadores ciclísticos:
    \begin{enumerate}
      \item Odômetro
      \item Relógio
      \item Velocidade média
      \item ...
    \end{enumerate}
  \end{itemize}
\end{frame}

\subsection{}
\begin{frame}
  \frametitle{Conclusão}
\begin{itemize}
 \item Extensões ao projeto
  \begin{enumerate}
   \item Atuador sobre \textit{derailleur dianteiro}
    \item Gerenciamento de energia
    \item Modificação dos parâmetros no \textit{runtime}
    \item Memória persistente
    \item Acelerômetro para inclinação do terreno
    \item ...
  \end{enumerate}

\end{itemize}

\end{frame}

\subsection{}
\begin{frame}

\vfil
\begin{center}
 \Large Perguntas?
\end{center}

\end{frame}

\end{document}

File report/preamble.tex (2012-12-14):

%
% preamble.tex - tex model of graduation work
% Version 0.1
%
% Author: Paulo S. Machado
% Date: June 2010
%
% Release under de GNU Public License v3.0 or greater
% This library is free software; you can redistribute it and/or
% modify it under the terms of the GNU General Public
% License as published by the Free Software Foundation; either
% version 3.0 of the License, or (at your option) any later version.
% 
% This template is distributed in the hope that it will be useful,
% but WITHOUT ANY WARRANTY; without even the implied warranty of
% MERCHANTABILITY or FITNESS FOR A PARTICULAR PURPOSE.  See the GNU
% General Public License for more details.
% 
% You should have received a copy of the GNU Lesser General Public
% License along with this template; if not, write to the Free Software
% Foundation, Inc., 51 Franklin St, Fifth Floor, Boston, MA  02110-1301  USA
%
% Language
\usepackage[portuges,brazil]{babel}
\usepackage[top=3cm,bottom=3cm,left=3.0cm,right=3cm]{geometry}
\usepackage[pdftex]{graphicx}
\usepackage{listings}
\usepackage{textcomp}
\usepackage{amssymb}
\usepackage{amsmath}
\usepackage{color}
\usepackage{mdwlist}
\usepackage{subfig}
% Encoding
\usepackage[utf8]{inputenc}

\linespread{1.3}

%\usepackage{wrapfig}
%\usepackage{hyperref}

% This will commands into the pdf to create a linked table of contents, as well
%as links for 
% the cross-references such as calls to figure and page numbers 
\usepackage[pagebackref=true]{hyperref}  
\hypersetup{
  pdftitle     = TG II - ES952 - Paulo Machado,
  pdfauthor    = Paulo Silveira Machado,
  colorlinks   = true,
  linkcolor    = black,
  anchorcolor  = red,
  citecolor    = blue,
  filecolor    = red,  
  urlcolor     = red
}

\DeclareGraphicsExtensions{.jpg,.jpeg,.png}
\graphicspath{{imagens/}}
% Heading foot
\usepackage{fancyhdr}
\pagestyle{fancy}
\headheight 15pt
\renewcommand{\sectionmark}[1]{\markright{\thesection\ #1}}
\rhead[\fancyplain{}{\bfseries\thepage}] %
    {\fancyplain{}{\bfseries\rightmark}}
\lhead{}
%\lhead[\fancyplain{}{\scshape\leftmark}] %
%    {\fancyplain{}{\bfseries\thepage}}
\cfoot{--~\thepage~--}

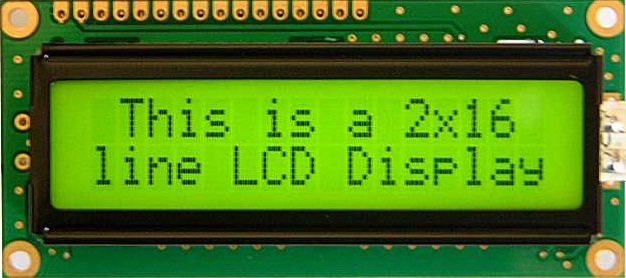
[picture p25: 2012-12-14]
report/imagens/jhd162a.jpg

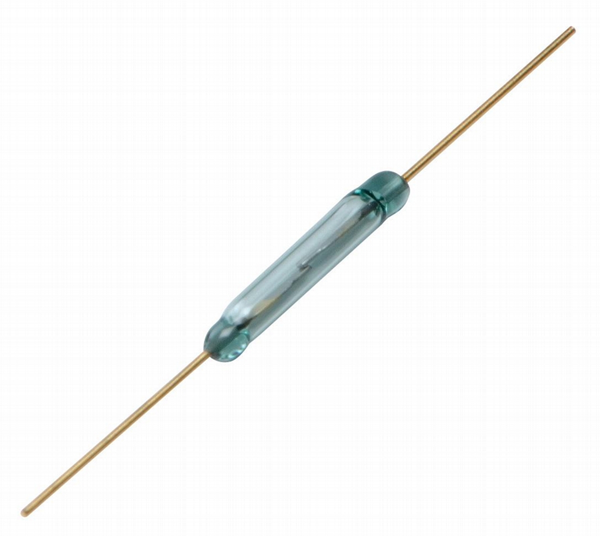
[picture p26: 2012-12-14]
report/imagens/reed3.jpg

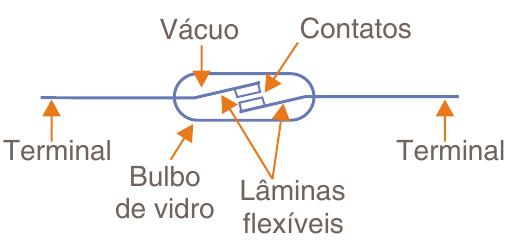
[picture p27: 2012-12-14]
report/imagens/figura_1_reed_switches.jpg

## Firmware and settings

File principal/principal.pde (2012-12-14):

/*
 * Main.pde - Main file to control a bicycle derailleur
 * Version 0.1
 *
 * This is file is part of a my final graduation work.
 * This code is intended to be used with an arduino to
 * automatically control gear changes of a commom
 * bicycle derailleur.
 *
 * Variables prefixed with "w" are referenced to wheel
 * Variables prefixed with "c" are referenced to the cadence
 *
 * Author: Paulo S. Machado
 * Date: October 2011
 *
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
 * You should have received a copy of the GNU Lesser General Public
 * License along with this library; if not, write to the Free Software
 * Foundation, Inc., 51 Franklin St, Fifth Floor, Boston, MA  02110-1301  USA
 */

#include <LiquidCrystal.h>
#include <BikeTransmission.h>
#include <Servo.h>



// Objects instatiation
Servo motor;
Derailleur trocador;
// lcd(RS,ENABLE,D4,D5,D6,D7)
LiquidCrystal lcd ( 7, 6, 5, 4, 8, 10 );
RearWheel roda ( 0.65 );  

// Constants
const int b0Pin = 11;   // K-
const int b1Pin = 12;   // K+
const int r0Pin = 3;    // Wheel
const int r1Pin = 2;    // Cadence
const int pwmPin = 9;   // PWM pin
const unsigned int CADENCE_MIN = 3000;  // MIN SPEED = MAX TIME coasting
const unsigned long RESET_TIMEOUT = 3000; // Timeout for reset timers
const int debugLevel = 2; // Set debug verbosity in serial

const int TOTAL_GEARS=6;
const int TOLERANCE=5;
const float validratios[TOTAL_GEARS]={1.0769, 1.2174, 1.4, 1.6471, 1.8667, 2.1538};

// Variables
unsigned int wspeed, state=1;
int gear=6;
float K=1.00;

float ratio;

// Interrupt used variables
volatile boolean w=false;
volatile boolean c=false;
volatile unsigned long ctime=0;
volatile unsigned long wtime=0;
volatile unsigned long ctimeLog[2];
volatile unsigned long wtimeLog[2];

/*
 * General pins and startup routine
 */
void setup() {
  Serial.begin ( 9600 );
  lcd.begin ( 16,2 ); 
  lcd.print( "start up..." );
  delay(2000); 
  lcd.clear(); 
  lcd.print ( "Vel:" );
  lcd.setCursor ( 8,0 ); 
  lcd.print ( "kmph" );
  lcd.setCursor ( 0,1 ); 
  lcd.print ( "Marcha:" );
  lcd.setCursor ( 10,1 ); 
  lcd.print ( "K:" );
  motor.attach ( pwmPin );
  pinMode ( b0Pin, INPUT );
  pinMode ( b1Pin, INPUT );
  pinMode ( r0Pin, INPUT );
  pinMode ( r1Pin, INPUT );
  attachInterrupt ( 1, wheel_monitor, FALLING );
  attachInterrupt ( 0, cadence_monitor, FALLING );
}

/*
 * Display refresh routine
 */
void update_lcd() {
  lcd.setCursor ( 4,0 );
  lcd.print("    ");
  lcd.setCursor ( 4,0 );
  lcd.print ( wspeed );
  lcd.setCursor ( 7,1 );
  lcd.print ( gear );
  lcd.setCursor ( 12,1 );
  lcd.print ( K );
}

/*
 * Serial debug output routine
 */
void update_serial() {
  if (debugLevel == 2) {
    Serial.print ( "Velocidade: " );    Serial.print ( wspeed ); Serial.println (" kmph");
    Serial.print ( "Marcha: " );        Serial.println ( gear );
    Serial.print ( "Tempo roda: " );    Serial.print ( wtime ); Serial.println ( " ms" );
    Serial.print ( "Tempo cadencia: " );Serial.print ( ctime ); Serial.println ( " ms" );
    Serial.print ("K: ");               Serial.println (K);     Serial.println ("");
  }
}

/*
 * Main loop
 */
void loop() {
  ratio=float(ctime)/wtime;
  for (int i=0;i<6;i++) {
      if (closeto(ratio,validratios[i],TOLERANCE)) {
          gear = i+1;
      }
  }
  
  // check if coasting
  if (( ctime < CADENCE_MIN ) && ( ctime != 0)) {
    // if not act over transmission
    trocador.set_gear ( motor, gear, ctime, wtime, K );
  }
  /*
   * Refresh displays
   */ 
  wspeed = roda.get_lspeed ( wtime );
  update_lcd();
  update_serial();
  /*
   * Button 1 read, k++
   */
  if ( digitalRead ( b1Pin ) == HIGH ) {
    K=K+0.01;
    if ( K >= 1.5 ) {
      K = 1.5;
    }
  }
  /*
   * Button 0 read, k--
   */
  if ( digitalRead ( b0Pin ) == HIGH ) {
    K=K-0.01;
    if ( K <= 0.5 ) {
      K = 0.5;
    }
  }
  delay ( 600 );
  reset_timers();
}

/*
 * wheel time interrupt
 * routine
 */
void wheel_monitor() {
  // first time log
  if ( w == false ) {
    wtimeLog[0] = millis();
    w=true;
  }
  else {
    wtimeLog[1] = millis();
    wtime = wtimeLog[1] - wtimeLog[0];
    wtimeLog[0] = wtimeLog[1];
  }
}

/*
 * cadence time interrupt
 * routine
 */
void cadence_monitor() {
  // first time log
  if ( c == false ) {
    ctimeLog[0] = millis();
    c=true;
  }
  else {
    ctimeLog[1] = millis();
    ctime = ctimeLog[1] - ctimeLog[0];
    ctimeLog[0] = ctimeLog[1];
  }
}

/*
 * timers reset routine
 */
void reset_timers() {
  unsigned long now = millis();
  if (now - wtimeLog[0] > RESET_TIMEOUT) {
    wtime = 0;
  }
  if (now - ctimeLog[0] > RESET_TIMEOUT) {
    ctime = 0;
  }
}

/*
 * Return true if param is within
 * tolerance [%] of reference:
 */
boolean closeto(float param, float reference, float tolerance) {
    return ( (param >= (reference*(100-tolerance)/100) ) &&
      (param <= (reference*(100+tolerance)/100) ) );
}

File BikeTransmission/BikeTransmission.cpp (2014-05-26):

/*
 * BikeTransmission.cpp - Bicycle Modeling Classes for Arduino
 * Version 0.1
 *
 * This is file is part of a my final graduation work.
 * This code is intended to be used with an arduino to
 * automatically control gear changes of a commom
 * bicycle Derailleur.
 *
 * Author: Paulo S. Machado
 * Date: October 2011
 *
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
 * You should have received a copy of the GNU Lesser General Public
 * License along with this library; if not, write to the Free Software
 * Foundation, Inc., 51 Franklin St, Fifth Floor, Boston, MA  02110-1301  USA
 */



#include "BikeTransmission.h"
#include <Servo.h>
#include <WProgram.h>
#include <math.h>

const int GEAR_MAX=6;
const int GEAR_MIN=1;
const int TOTAL_PATH=180;
const int TOTAL_GEARS=6;
const int STEP=TOTAL_PATH/TOTAL_GEARS;
const int TOLERANCE=0.05;
const float validratios[TOTAL_GEARS]={1.0769, 1.2174, 1.4, 1.6471, 1.8667, 2.1538};

// Time limits (milliseconds)

const int CADENCE_MIN=1600;
/// 90RPM - 667ms
const int CADENCE_MAX=667;

// Offset in the derailleur moviment to engage next gear
const float UP_OFFSET=0.9;
const float DOWN_OFFSET=1.1;

/********* Constructors implementation ************/
RearWheel::RearWheel ( float _diameter ) {
    this->diameter = _diameter;
}


/*********** Methods implementation **************/


/**
 * Linear wheel speed calculated with: \n
 * \f$V = \omega r = 2\pi fr \f$\n
 * \f$V = \frac{\pi*D}{T} [m/ms] \f$\n
 * \f$V = \frac{3.6*1000*\pi*D}{T} [km/h] \f$
 */
int RearWheel::get_lspeed ( unsigned long T ) {
    int lspeed;
    // condition to speed less than 1km/h
    if ( ( T > 7350 ) || ( T == 0 ) ) return 0;
    lspeed = round( (1000*3.6*3.1416*(this->diameter))/T );
    return( lspeed );
}

/**
 * Return true if param is within
 * tolerance [%] of reference:
 */
boolean closeto2(float param, float reference, float tolerance) {
    return (( param >= (reference*(1.00-tolerance)) ) &&
      ( param <= (reference*(1.00+tolerance)) ));
}

/**
 * Return the current gear based on known
 * gear ratios and revoltion times. \n
 * TODO: Discover why this dont work
 *      inside the library
 */
int Derailleur::get_gear ( unsigned long c_t, unsigned long w_t ) {
    float ratio;
    ratio=float(c_t)/w_t;
    for (int i=0;i<TOTAL_GEARS;i++) {
        if (closeto2(ratio,validratios[i],TOLERANCE)) {
            return(i+1);
        }
    }
}

/*
 * Class core method. Choose whatever the gear should be changed. 
 */
void Derailleur::set_gear ( Servo motor, int gear, long int c_t, long int w_t, float K ) {
    int cur_position = motor.read();
    int target_positon = round(STEP*gear);
    // make sure that derailleur is at expected position
    if (cur_position != target_positon) {
        motor.write(target_positon);
    }
    else {
        if ( ( c_t > CADENCE_MIN*K ) && ( gear != GEAR_MIN ) ) {
            // Hold position a little lower for a little time
            motor.write (round( STEP* ( gear - 1 ) *UP_OFFSET ));
            Serial.println("Mais torque!");
            delay(700);
            // and then leave in best position
            motor.write ( STEP* ( gear - 1 ) );
        } else if ( ( c_t < CADENCE_MAX*K ) && ( gear != GEAR_MAX ) ) {
            // Hold position a little higher for a little time
            motor.write (round( STEP* ( gear + 1 ) *DOWN_OFFSET ));
            Serial.println("Mais velocidade...");
            delay(700);
            // and then leave in best position
            motor.write ( STEP* ( gear + 1 ) );
        }
    }
}

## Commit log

2010-04-30 Several changes. Redesign it all with constant reference to the phisical model
    [BikeTransmission.cpp]
2010-05-04 Added first implementation of pwm motor manipulation and set criteria.
2010-05-10 Defininf intervals to gear analysis (get_gear)
2011-04-29 Last changes from working prototype
2011-04-29 helper filter calculation python script is back
2011-10-11 * Renamed main file * Fix pins lcd configuration (lcd cannot use pins 0 and 1 with serial)
    [principal.pde]
2011-10-12 Added more comments and timers reset routine
    [principal.pde]
2011-10-12 Fix linear speed calculation. Removed tabs and deprecated code
    [BikeTransmission.cpp]
2011-10-14 Repository of svg circuit parts
2011-10-14 Using absolute size to image in frontpage and add circuit schema
2011-10-17 Removing redundancies and put gear discovery into main code
2011-10-28 Addition on conclusion and intro. Today I discover that it's not going to work the way it is. I need more torque
2011-10-29 Added actuator assembly steps
2011-11-02 Deliver version - tested on real system. Seems to work, but the servo is not strong enough
2012-06-11 Added logic diagram and schematics
    [TGII.fzz]
2012-12-14 random stuff
    [TGII.fzz]
